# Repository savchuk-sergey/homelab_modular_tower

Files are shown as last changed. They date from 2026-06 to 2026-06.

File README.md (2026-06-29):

# Homelab Modular Tower

Parametric CadQuery engineering project for a compact 3D-printed homelab stack.

The project is engineering-first: revision-scoped specifications, explicit validation gates, serviceable module architecture, four M5 through-rods where applicable, rear service routing, low-voltage DC power planning, and Mini PC cooling priority.

Do not start CAD implementation from root `README.md` alone. Always validate the active revision-scoped specification first.

---

## Current active engineering focus: mk0.12

Active revision: `mk0.12 MVP-2M stack-through-rod`

`mk0.12` is an MVP-2M revision, not a full final tower and not a hot-swappable blade chassis. The active real modules are:

- Raspberry Pi + SSD
- Mini PC

The active architecture is stack-through-rod:

- modules are stacked on four M5 rods;
- top and bottom washers/nuts compress the stack;
- a middle module cannot be removed without loosening the stack;
- this is an accepted MVP limitation documented in the revision-scoped specification;
- primary device installation and cable routing happen before final stack compression.

### Current mk0.12 status

```text
SPECIFICATION: PASS FOR CAD SKELETON V3 INPUT
CAD IMPLEMENTATION: NOT STARTED
COUPON PARTS: BLOCKED
FULL PRINT: BLOCKED
NEXT STEP: mk0.12 CAD skeleton cleanup v3
```

The next engineering step remains `mk0.12 CAD skeleton cleanup v3`, but only after the cleanup/spec workflow is accepted. Documentation-only work must not advance `CAD IMPLEMENTATION` beyond `NOT STARTED`.

### mk0.12 read order

1. `revisions/mk0.12/README.md`
2. `revisions/mk0.12/ENGINEERING_SPEC.md`
3. `revisions/mk0.12/PARTS_SPEC.md`
4. `revisions/mk0.12/INTERFACES.md`
5. `revisions/mk0.12/VALIDATION_GATES.md`
6. `revisions/mk0.12/AGENT_RULES.md`
7. `revisions/mk0.12/PHYSICAL_TEST_PLAN.md`
8. `revisions/mk0.12/KNOWN_ISSUES.md`

If those documents are missing, incomplete, contradictory, or structurally invalid, CAD work is blocked.

---

## Source-of-truth policy

For active engineering work, source-of-truth precedence is:

1. Revision-scoped documents under `revisions/<revision>/`.
2. Root `AGENTS.md` workflow rules.
3. Legacy/reference snapshots.
4. Derived artifacts such as STEP, STL, PNG, screenshots, slicer previews, and renders.

CadQuery source files in `cad/` are the CAD source of truth. STEP/STL exports, renders, drawings, screenshots, and slicer previews are generated artifacts and must not override CadQuery source or revision-scoped specifications.

---

## Repository structure

```text
homelab_modular_tower/
  AGENTS.md                        # LLM agent workflow and hard gates
  README.md                        # repository orientation

  cad/                             # active CadQuery source
    config.py                      # parametric dimensions and revision constants
    parts/                         # part builders
    assembly/                      # assembly builders
    exporters/                     # export infrastructure
    utils/                         # geometry helpers

  revisions/
    mk0.12/                        # active revision-scoped specification
      README.md
      ENGINEERING_SPEC.md
      PARTS_SPEC.md
      INTERFACES.md
      VALIDATION_GATES.md
      PHYSICAL_TEST_PLAN.md
      AGENT_RULES.md
      KNOWN_ISSUES.md
    mk0.11/                        # historical/superseded subsystem-first workflow
    mk0.1/ ... mk0.9.3/            # historical revision documentation

  docs/
    workflow/
      subsystem_first_workflow.md  # mk0.11 historical/superseded workflow reference
    KIMI_AGENTS_SWARM_PROMPT_GUIDE.md
    ARCHITECTURE.md
    BOM.md
    POWER.md
    PRINTING.md

  reviews/                         # historical review reports and agent outputs
  drawings/                        # drawing/reference artifacts
  exports/                         # generated STEP/STL artifacts
  renders/                         # generated render artifacts
  scripts/                         # validation/export/render/review helpers
```

---

## Historical workflow note

`mk0.11` used a subsystem-first / testable CAD-first workflow. That workflow is now historical/superseded for active work unless a future revision explicitly promotes it again.

Useful historical references:

- `revisions/mk0.11/README.md`
- `revisions/mk0.11/VALIDATION_PLAN.md`
- `revisions/mk0.11/DECISIONS.md`
- `docs/workflow/subsystem_first_workflow.md`
- `drawings/mk0.10/README.md` for the cancelled drawing-first planning context

Historical documents must not be treated as active `mk0.12` requirements when they conflict with the revision-scoped `mk0.12` specification. The stricter interpretation wins until the ambiguity is resolved.

---

## Install

CadQuery is the only non-standard CAD dependency.

```powershell
python -m pip install cadquery
```

If you use Conda, the CadQuery project recommends a Conda environment:

```powershell
conda create -n cadquery cadquery -c conda-forge
conda activate cadquery
```

---

## Safe documentation checks

For documentation-only cleanup, use safe git/markdown checks only:

```powershell
git diff --stat
git diff -- README.md AGENTS.md revisions/mk0.12
```

Do not run the CAD export pipeline, render generation, STEP/STL generation, or coupon-part generation as part of documentation cleanup.

---

## CAD revision workflow

The hard gate is defined in `AGENTS.md`:

1. Complete the revision-scoped specification.
2. Validate required document structure.
3. Validate internal consistency.
4. Mark conflicts, assumptions, and unverifiable requirements explicitly.
5. Only after valid specification: allow CAD planning.
6. Only after CAD planning: allow CadQuery implementation.
7. Only after CAD validation gates: allow coupon parts.
8. Only after coupon and physical tests: allow full print.

No CAD development is allowed until the active revision specification is structurally complete and internally consistent.

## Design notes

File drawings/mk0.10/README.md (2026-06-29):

# mk0.10 Architecture Drawings — CANCELLED / LEGACY

> **Status: CANCELLED — drawing-first workflow stopped.**
>
> These SVG files are planning artifacts from the mk0.10 drawing-first
> workflow iteration. That workflow has been cancelled.
>
> **Do not continue iterating these drawings.**
> **Do not use these drawings as the source for active CAD decisions.**
>
> See `revisions/mk0.11/DECISIONS.md` — Decision D-001 for the full rationale.
> See `revisions/mk0.11/README.md` for the historical mk0.11 subsystem-first workflow.
> For current mk0.12 work, use `revisions/mk0.12/README.md` and root `AGENTS.md`.

---

## Why this workflow was cancelled

The mk0.10 SVG iteration produced technically correct but visually flat drawings
with no engineering judgment built in. Iterating on them did not unlock any design
decision that could not be read directly from `cad/config.py`. Physical prototyping
produces faster and more reliable validation than SVG drawing iteration for this
type of project.

## What these files are

| File | Sheet | Description |
|---|---|---|
| `01_architecture_layout_front.svg` | Sheet 01 | Front elevation layout |
| `02_architecture_layout_side.svg` | Sheet 02 | Side elevation layout |
| `03_module_interface_top.svg` | Sheet 03 | Module interface — top view |
| `04_module_interface_section.svg` | Sheet 04 | Module interface — cross section |
| `05_rail_carriage_section.svg` | Sheet 05 | Rail / carriage cross section |

Generated by: `scripts/generate_architecture_drawings.py` (also cancelled / legacy).

## Preservation policy

These files are preserved for historical reference.
They are not deleted, but they will not be updated.
CadQuery (`cad/config.py`) remains the source of truth for all dimensions.

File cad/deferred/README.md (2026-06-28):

# Deferred / future CAD — mk0.11 sliding carriage / rail subsystem

This folder documents and re-exports CAD that belongs to the **deferred**
sliding carriage / rail architecture.  It is preserved for future upgrade
paths but is **not active** in mk0.11.2.

## Active architecture (mk0.11.2)

`base_pedestal` + `generic_stack_module` + `top_cap`, compressed by four M5
through-rods.  See `revisions/mk0.11.2/`.

## Deferred architecture (future)

Sliding open-frame carriage on aluminum U-channel rails with POM-C shoes.
Source files remain in their original locations under `cad/parts/` and
`cad/assembly/` for backward compatibility and future rail/carriage work.

### Deferred parts

| Part | Source |
|---|---|
| `generic_module` (carriage-era shell with rail pockets) | `cad/parts/generic_module.py` |
| `generic_module_carriage` | `cad/parts/module_carriage.py` |
| `u_channel_rail_generic_module` | `cad/parts/rail_profile.py` |
| `pom_c_shoe_reference` | `cad/parts/pom_shoe.py` |

### Deferred assemblies

| Assembly | Source |
|---|---|
| `generic_module_assembly` | `cad/assembly/generic_module_assembly.py` |
| `single_module_bay_assembly` | `cad/assembly/single_module_bay_assembly.py` |

### Deferred jigs

| Jig | Source |
|---|---|
| `rail_carriage_fit_test` | `cad/jigs/rail_carriage_fit_test.py` |

## Rules

- Do not delete deferred code.
- Do not change the frozen U-channel rail standard when reactivating this path.
- Stack modules reserve future adapter zones in `generic_stack_module.py` so
  deferred carriage hardware can attach later without a full module redesign.

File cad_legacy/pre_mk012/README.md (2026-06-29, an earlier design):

# pre_mk012 CAD Legacy Archive

This directory contains CAD and CAD-pipeline files that were active before the
mk0.12 MVP-2M pre-CAD implementation cleanup.

These files are preserved for engineering history only.  They are not part of
the active mk0.12 CAD implementation path.

Active mk0.12 pre-CAD files live in:

- `cad/__init__.py`
- `cad/config.py`
- `scripts/validate_mk012_spec.py`

Do not import files from this archive into the active CAD path without an
explicit revision decision.

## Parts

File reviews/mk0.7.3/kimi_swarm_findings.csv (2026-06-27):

finding_id | severity | evidence_status | reference | affected_parts | description | why_it_matters | recommended_action
MA-003 | BLOCKER | CONFIRMED | cad/parts/service_spine.py:8-35; part_dimensions.csv | rear_service_spine_lower,rear_service_spine_upper,rear_service_spine_cover_lower,rear_service_spine_cover_upper,power_bus_panel_lower,power_bus_panel_upper,power_bus_cover_lower,power_bus_cover_upper | Both lower and upper split segments have alignment tabs at the same Z=0 location. When assembled, tabs occupy the same physical volume. | Split sections are designed to be bolted together. If tabs collide, the joint cannot be assembled. This is impossible geometry, not a fit risk. | Redesign _split_section() so only one segment has a tab and the other has a matching slot. Remove the tab from the upper segment. MA-004,BLOCKER,CONFIRMED,cad/parts/cooling.py:113-134; config.py" | bottom_filter_retainer | Corner clips are placed at Y=±61, but the retainer body is only 8 mm deep (Y=±4). Clips are 57 mm outside the body and completely detached. | The retainer's only function is to hold the filter sheet. Detached clips cannot exert any retention force. The part is non-functional as printed. | Attach clips to the retainer body with connecting geometry, or redesign the retention mechanism (e.g., sliding rail clips). ASM-001,HIGH,CONFIRMED,cad/parts/side_panels.py:198-220; tower_assembly.py:159-212; renders/assembly/left.png" | left_side_panel_lower,left_side_panel_middle,left_side_panel_upper | Left and right panels share identical geometry. Both are rotated +90° around Z. For the left panel at X=-96.5, local +Y maps to -X_global = outward. Ribs and mounting bosses face away from the tower. | The left panel mounting bosses are on the exterior (X≈-108), while the mount rail is on the interior (X=-91). There is a ~13 mm gap with no boss support. The screw head would be exposed on the exterior, requiring an overly long screw. | Change left panel rotation to -90.0° (or 270.0°) in tower_assembly.py, or create mirrored left-panel geometry in side_panels.py. MA-002,HIGH,CONFIRMED,cad/parts/rails.py:31-45; tower_assembly.py:45-58; config.py" | rail_end_mount (8 instances),metal_guide_rail | Bottom mount at Z=3.5, rail starts at Z=5.0. Mount slot is 10.8 mm tall. Rail engages only 3.5 mm of the slot. Top mount has the same 3.5 mm overlap. | 3.5 mm engagement may be insufficient to securely capture the rail end. The mount may slide off or wobble under tray load. This is a shallow engagement risk, not a complete miss. | Either move the bottom mount to Z=5.0+ so the rail starts inside the slot, or increase the slot depth to 15+ mm. ASM-002,HIGH,LIKELY,cad/parts/side_panels.py:100-113; tower_assembly.py:159-212; part_dimensions.csv" | right_side_panel_lower,right_side_panel_upper,side_panel_mount_rail | After +90° rotation, the right panel's +Y face is at X=+85 (inward). Mounting bosses extend from X=+85 to X=+91.0 (for 4 mm rib height). The mount rail is at X=+91, from +87 to +95. The bosses overlap the rail volume. | If the bosses and ribs occupy the same space as the mount rail, the parts cannot be assembled without collision. Needs verification in CAD or a physical coupon. | Verify exact boss and rib placement relative to the rail in side_panels.py. If overlap is real, reduce rib height near the rail zone or add cutouts. PE-008,HIGH,CONFIRMED,plastic_estimate.csv (sum of all rows)" | All printable plastic parts | 42 printable plastic parts total 3,732 g mesh solid volume. With slicer infill, perimeters, supports, and purge, this translates to ~4.5–5.5 kg of actual PETG filament. | For a fit-check rough mockup, this is uneconomical and slow. Print time is estimated at 80–120 hours. At typical PETG pricing, this is $90–140 in filament. | Introduce mockup-thickness parameters (e.g., MOCKUP_BASE_THICKNESS=6.0, MOCKUP_TRAY_BASE=2.0) and reduce central_bottom_fan_frame, stability wings, and tray walls for mockup prints only. PRINT-004,HIGH,LIKELY,printability_check.csv (aspect_ratio=47.5); part_dimensions.csv" | top_fan_grille | 190 × 190 × 4 mm, aspect ratio 47.5. Large thin flat part with very low thermal mass. | Corners will cool fast and contract aggressively. PETG corner lift is nearly guaranteed on a 190 mm span without aggressive bed adhesion measures. | Print flat with generous brim (10 mm+). Reduce part cooling fan to 30–40 %. Use enclosure or draft shield. Consider mouse ears at corners. PRINT-005,HIGH,LIKELY,printability_check.csv (aspect_ratio=46.0); part_dimensions.csv" | bottom_filter_frame | 138 × 138 × 3 mm, aspect ratio 46.0. Very thin sheet. | Same category as the grille: large, thin, flat. 3 mm thickness with 138 mm span is extremely prone to corner lifting in PETG. | Print flat with full brim or mouse ears at corners. No supports needed. PRINT-011,HIGH,LIKELY,part_dimensions.csv; config.py (TRAY_BASE_THICKNESS=3.0)" | external_ssd_bay,mikrotik_tray,mini_pc_tray,raspberry_pi_tray,ssd_expansion_tray,ups_power_tray | All six trays have a 3 mm base with a 172–186 × 178 mm footprint. | PETG will warp at corners on any part with a large thin base. The tray base is the single biggest warping risk in the entire project. | Mandatory brim (8–10 mm). Enclosure or heated chamber highly beneficial. Slow first layer. No supports needed for vertical walls. RAP-001,HIGH,CONFIRMED,tower_assembly.py:61-69; part_dimensions.csv" | tray_support_ledge (24 instances) | Six trays × four rails = 24 small ledges that must be placed at unique Z heights and fastened individually. | This is the highest-risk step for misassembly. A human must track 24 small parts, place them at exact heights, and fasten each without a jig or alignment helper. Disproportionately complex for a rough mockup. | Reduce to a single continuous rail support per side, or design a printed installation jig/caliper that indexes off the frame. RAP-004,HIGH,CONFIRMED,PRINTABLE_PARTS.md; NON_PRINTABLE_PARTS.md; PLACEHOLDERS.md; assembly.png" | All parts | With 109 part instances from 42 unique designs, a human cannot reliably infer build order from Python code alone. | Critical steps like rod threading, base-section bolting, and mount-rail insertion order are completely undocumented. This is a recipe for misassembly and frustration. | Produce a numbered assembly instruction sheet with stage gates (e.g., Base → Rods → Corner Blocks → Rails → Ledges → Trays → Spine → Panels → Fans → Feet). PRINT-007,HIGH,LIKELY,part_dimensions.csv" | rear_service_spine_lower,rear_service_spine_upper | 132 × 40.5 × 157.75 mm. Tall, narrow PETG print with a small footprint. | Tall narrow prints are prone to gantry-induced wobble and can detach from the bed due to leverage. 157 mm is a significant height for a narrow base. | Print with wide brim (10 mm). Slow outer wall speed (30–40 mm/s). Ensure bed is clean. Consider a raft for the lower section. PRINT-019,HIGH,LIKELY,part_dimensions.csv" | rear_service_spine_cover_lower,rear_service_spine_cover_upper | 46 × 6 × 156.75 mm. 156 mm tall with only 6 mm base thickness. | This is a very tall thin wall. If printed upright on the 46 × 6 face, PETG will almost certainly wobble or detach. | Strongly recommend printing on the 46 × 156.75 face (Z = 6 mm). This makes the part a flat plate with short layer height. Use a generous brim. PE-001,HIGH,CONFIRMED,plastic_estimate.csv (326.43 g); part_dimensions.csv (257 | 031 mm³)" | central_bottom_fan_frame | 190 × 190 × 16 mm base plate. This is 60% thicker than the BASE_STABILITY_THICKNESS=10.0 used elsewhere. | This single part consumes 8.7% of all printable plastic. The M5 rods provide the primary vertical load path. The central frame only needs to distribute the 120 mm fan mount load and support a filter frame.
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

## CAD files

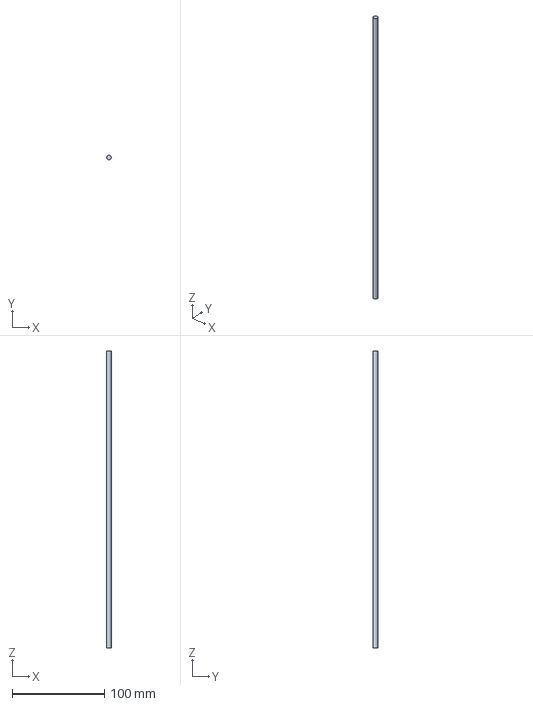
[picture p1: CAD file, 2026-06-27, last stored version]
revisions/mk0.7/review_package/exports/non_printable/metal_reference/m5_threaded_rod.step
5.00 x 5.00 x 321.5 mm

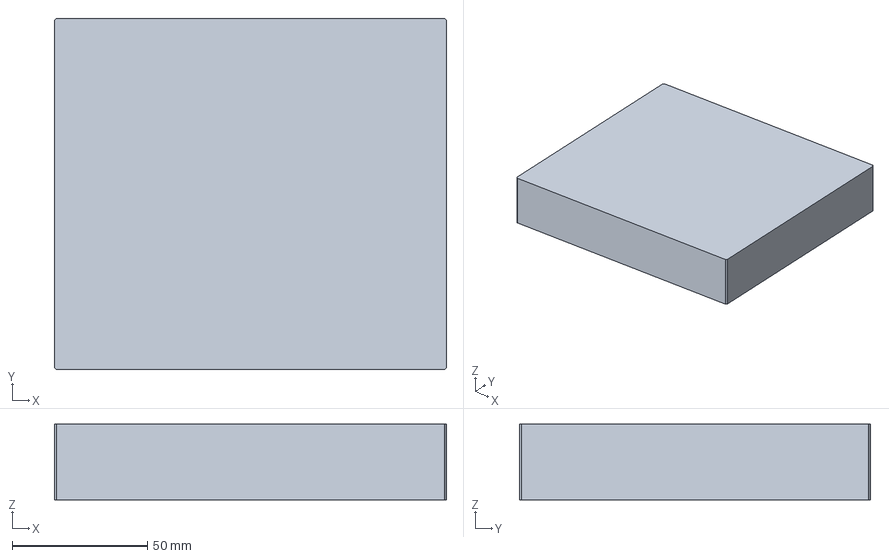
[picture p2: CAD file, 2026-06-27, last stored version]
revisions/mk0.7/review_package/exports/placeholders/devices/mini_pc_placeholder.step
145.0 x 130.0 x 28.0 mm

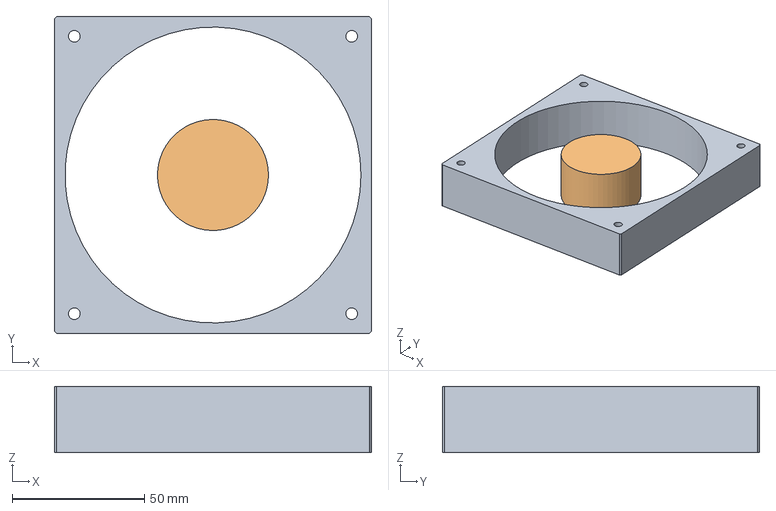
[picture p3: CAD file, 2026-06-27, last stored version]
revisions/mk0.7/review_package/exports/placeholders/fans/fan_120x120x25_placeholder.step
120.0 x 120.0 x 25.0 mm

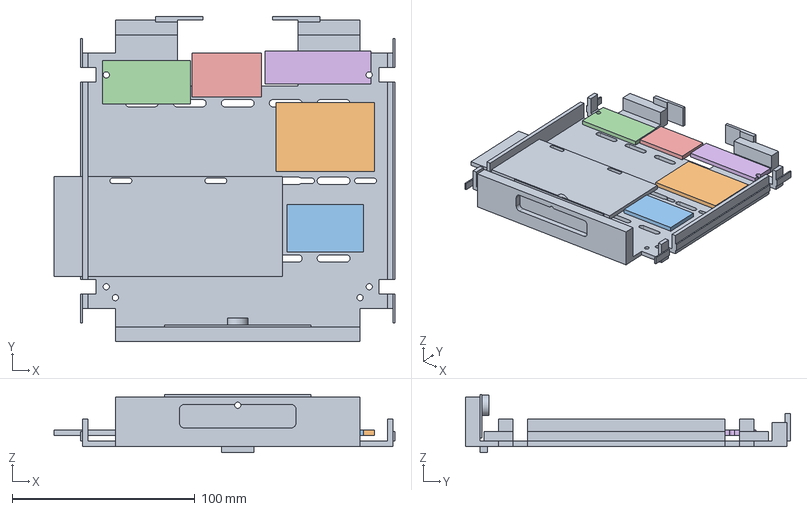
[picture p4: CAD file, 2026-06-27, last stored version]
revisions/mk0.7/review_package/exports/printable/plastic/ups_power_tray.step
186.5 x 178.0 x 32.0 mm

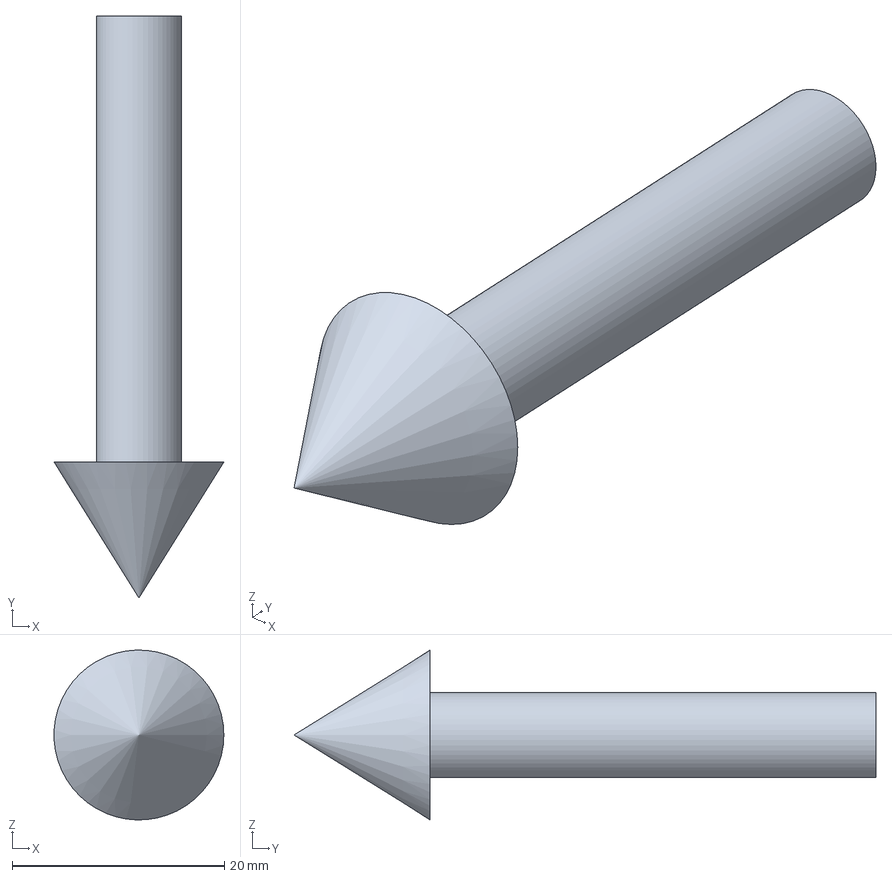
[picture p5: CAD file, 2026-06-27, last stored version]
revisions/mk0.7/review_package/exports/review/mini_pc_airflow_path_review.step
16.0 x 54.8 x 16.0 mm

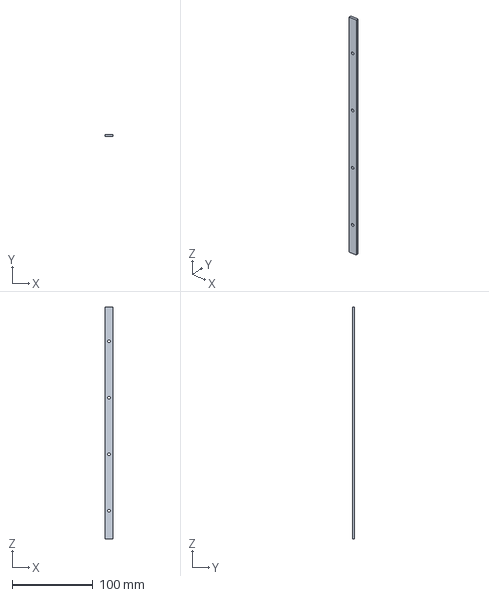
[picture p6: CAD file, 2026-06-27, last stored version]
revisions/mk0.7/review_package/exports/non_printable/metal_reference/metal_guide_rail.step
10.0 x 3.00 x 287.5 mm

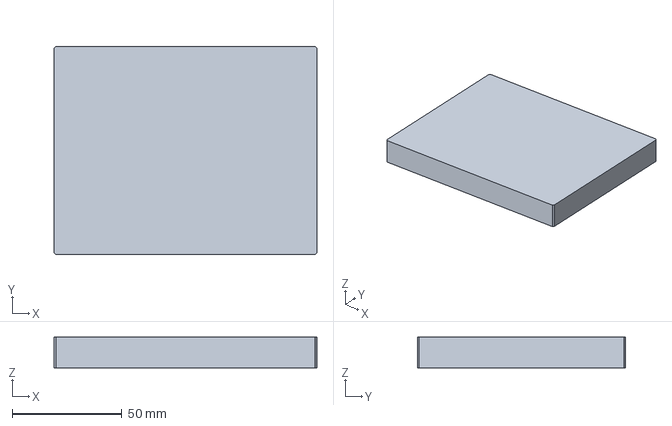
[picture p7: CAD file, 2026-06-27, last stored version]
revisions/mk0.7/review_package/exports/placeholders/devices/mikrotik_placeholder.step
120.0 x 95.0 x 14.0 mm

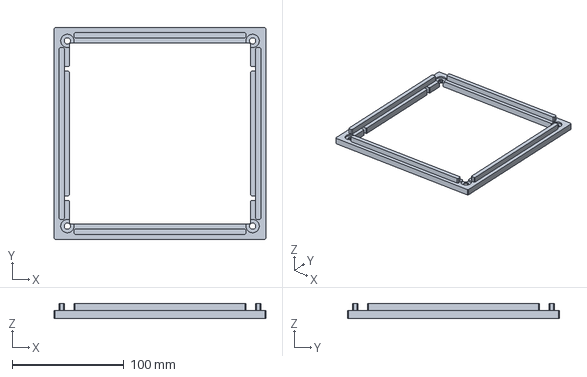
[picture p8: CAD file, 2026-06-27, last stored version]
revisions/mk0.7/review_package/exports/printable/plastic/bottom_structural_frame.step
190.0 x 190.0 x 13.0 mm

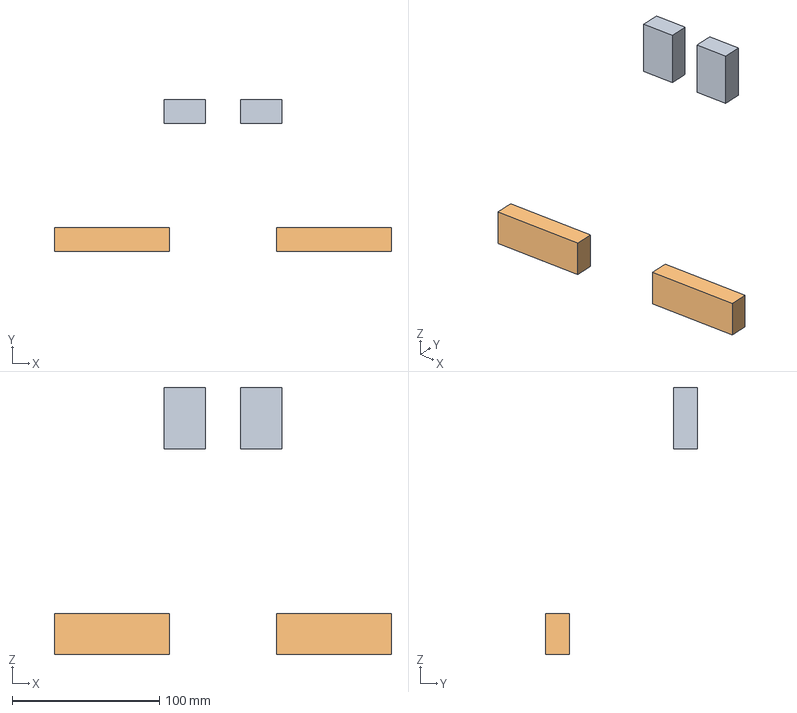
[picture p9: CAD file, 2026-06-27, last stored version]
revisions/mk0.7/review_package/exports/review/blocked_air_zones_review.step
229.0 x 103.0 x 181.8 mm

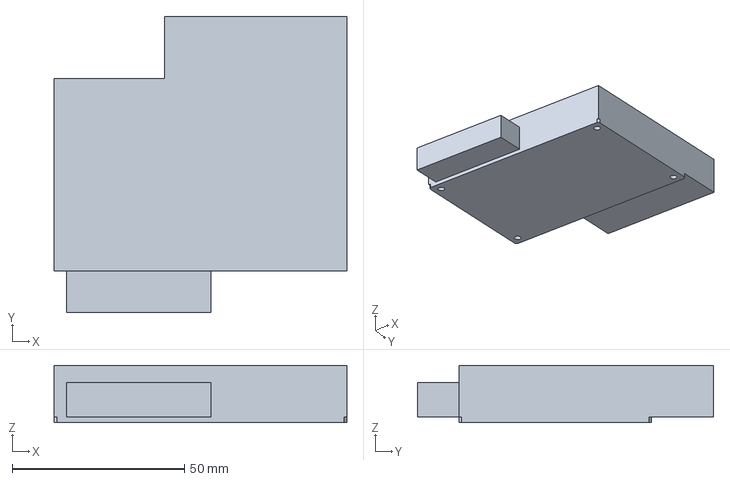
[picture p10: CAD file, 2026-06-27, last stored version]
revisions/mk0.7/review_package/exports/placeholders/devices/raspberry_pi_3b_placeholder.step
85.0 x 86.0 x 16.6 mm

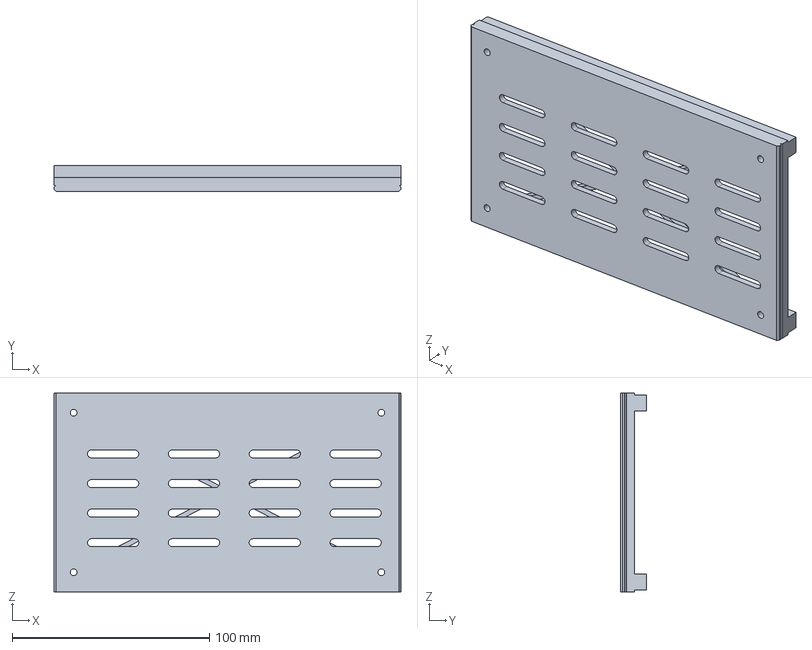
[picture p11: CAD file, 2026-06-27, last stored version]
revisions/mk0.7/review_package/exports/printable/plastic/right_side_panel_lower.step
176.0 x 13.0 x 100.9 mm

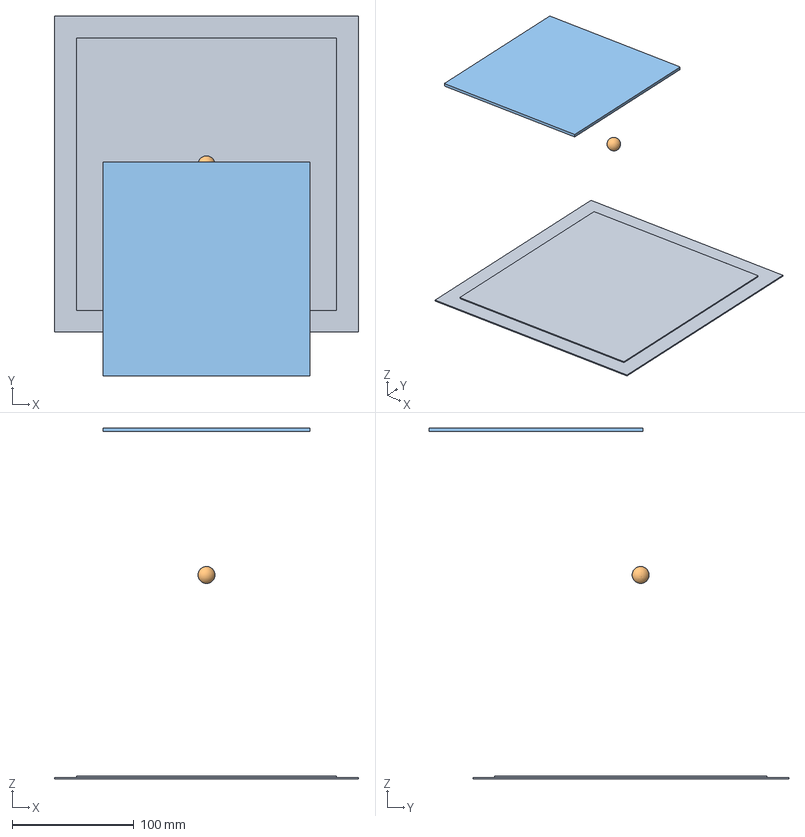
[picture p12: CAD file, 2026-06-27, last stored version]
revisions/mk0.7/review_package/exports/review/stability_review.step
250.0 x 296.0 x 288.6 mm

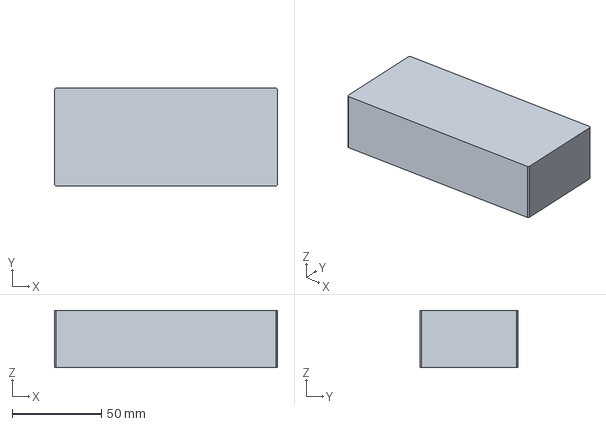
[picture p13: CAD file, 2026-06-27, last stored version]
revisions/mk0.7/review_package/exports/placeholders/devices/ups_placeholder.step
125.0 x 55.0 x 32.0 mm

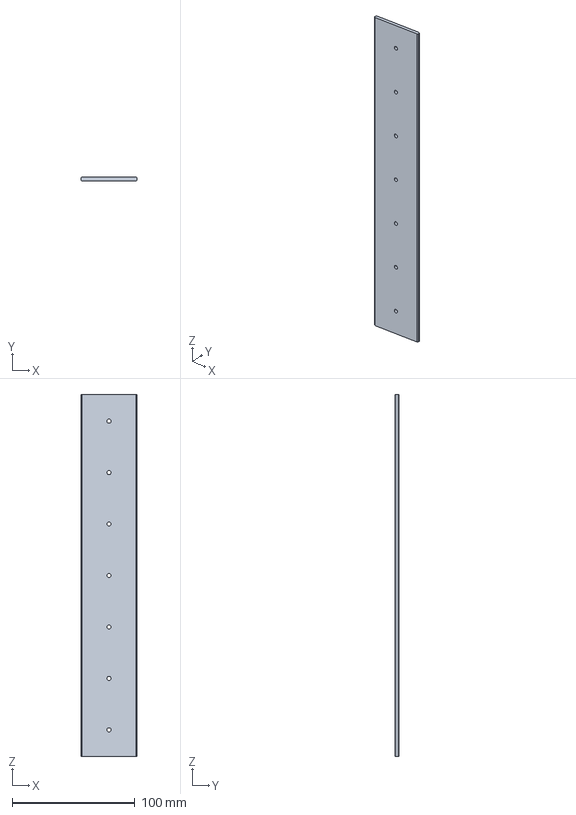
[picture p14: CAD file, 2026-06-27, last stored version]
revisions/mk0.7/review_package/exports/printable/plastic/rear_service_spine_cover.step
46.0 x 3.00 x 295.5 mm

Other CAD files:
revisions/mk0.7/review_package/exports/review/airflow_path_review.step
revisions/mk0.7/review_package/exports/placeholders/devices/ssd_expansion_placeholder.step
revisions/mk0.7/review_package/exports/printable/plastic/mini_pc_tray.step
revisions/mk0.7/review_package/exports/review/printability_layout_review.step
exports/mk0.1/step/bottom_fan_panel.step
exports/mk0.1/step/corner_block.step
exports/mk0.1/step/external_ssd_bay.step
exports/mk0.1/step/frame_bottom.step
exports/mk0.1/step/frame_top.step
exports/mk0.1/step/left_side_panel.step
exports/mk0.1/step/m5_threaded_rod.step
exports/mk0.1/step/metal_guide_rail.step
exports/mk0.1/step/mikrotik_tray.step
exports/mk0.1/step/mini_pc_airflow_duct.step
exports/mk0.1/step/mini_pc_tray.step
exports/mk0.1/step/power_bus_panel.step
exports/mk0.1/step/raspberry_pi_tray.step
exports/mk0.1/step/rear_service_spine.step
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

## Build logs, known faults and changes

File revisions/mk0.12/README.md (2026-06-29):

# mk0.12 - Revision Map

Revision: mk0.12  
Architecture: MVP-2M stack-through-rod  
Status: Revision-scoped document set active for CAD skeleton v3 input  

Related documents:
- README.md
- ENGINEERING_SPEC.md
- PARTS_SPEC.md
- INTERFACES.md
- VALIDATION_GATES.md
- PHYSICAL_TEST_PLAN.md
- AGENT_RULES.md
- KNOWN_ISSUES.md

## Status

```text
SPECIFICATION: PASS FOR CAD SKELETON V3 INPUT
CAD IMPLEMENTATION: NOT STARTED
COUPON PARTS: BLOCKED
FULL PRINT: BLOCKED
NEXT STEP: mk0.12 CAD skeleton cleanup v3
```

## Architecture

mk0.12 is an MVP-2M stack-through-rod architecture for a compact Homelab Modular Tower. The active stack is:

1. `base_pedestal`
2. `rpi_ssd_stack_module`
3. `minipc_stack_module`
4. `top_cap`

The tower uses a frozen 190 x 190 mm footprint, four M5 rods at X/Y +/-80, and a 238 mm stack height. It is not a hot-swappable blade chassis. Primary device installation and cable routing must happen before final stack compression.

Coupon parts and full print are blocked until the CAD skeleton v3 validation gates pass. Physical coupons follow CAD validation; full print follows coupon and physical validation.

## Read Order

1. ENGINEERING_SPEC.md
2. PARTS_SPEC.md
3. INTERFACES.md
4. VALIDATION_GATES.md
5. AGENT_RULES.md
6. PHYSICAL_TEST_PLAN.md
7. KNOWN_ISSUES.md

## Legacy Snapshot

`MVP_ENGINEERING_SPEC.md` remains as the consolidated legacy snapshot. These revision-scoped documents split that content by purpose without changing engineering decisions. If a requirement appears ambiguous, preserve the stricter interpretation and verify against `MVP_ENGINEERING_SPEC.md`.

The revision-scoped documents are the active source of truth for new mk0.12 CAD work.
`MVP_ENGINEERING_SPEC.md` is fallback/context only.
If the legacy snapshot conflicts with the revision-scoped documents, the revision-scoped documents win.
If ambiguity remains, preserve the stricter interpretation and validate against `VALIDATION_GATES.md`.

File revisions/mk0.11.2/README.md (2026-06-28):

# mk0.11.2 — Stack-Through-Rod Architecture

## Scope

mk0.11.2 corrects the ambiguous carriage/module direction from mk0.11 and
mk0.11.1.  The first physical prototype is a **layer-cake stack** compressed
by four M5 through-rods — not a sliding carriage prototype.

### Active architecture

```text
base_pedestal
  + generic_stack_module(s)
  + top_cap
  -> compressed by 4x M5 through-rods
```

Stack modules are printable PETG layers with:

- top/bottom interface rings and alignment features;
- M5 pass-through holes at corner posts;
- local washer compression pad zones;
- central vertical airflow opening;
- rear service reserved zone;
- internal device mounting placeholder grid;
- front handle / label zone placeholder;
- **future** carriage / side-adapter mounting zones (pads + M3 bosses only).

Primary validation assembly: `stack_test_assembly`.

### Deferred architecture

Sliding open-frame carriage on aluminum U-channel rails with POM-C shoes.
Source code is preserved under `cad/deferred/` and original part paths.
Not exported or validated as part of mk0.11.2.

---

## CAD targets (mk0.11.2)

| Target | Source |
|---|---|
| `generic_stack_module` | `cad/parts/generic_stack_module.py` |
| `base_pedestal` | `cad/parts/base_pedestal.py` |
| `top_cap` | `cad/parts/top_cap.py` |
| `stack_test_assembly` | `cad/assembly/stack_test_assembly.py` |

Export:

```text
python -m cad.export --revision mk0.11.2
```

---

## Out of scope

- Full tower CAD integration
- Active carriage, rails, or POM-C shoe sockets in stack modules
- UPS / router / Mini PC module finalization
- Rear Service Spine revision
- Changes to the frozen U-channel rail standard
- Solid floors blocking vertical airflow

---

## Relationship to prior mk0.11.x work

| Revision | Status |
|---|---|
| mk0.11 | Subsystem-first workflow; carriage/rail generic module — **superseded for active prototype** |
| mk0.11.1 | Branch work toward carriage validation — **not active in mk0.11.2** |
| mk0.11.2 | **Active**: stack-through-rod prototype with future adapter reserve |

Historical mk0.11 files (`generic_module.py`, `module_carriage.py`, bay
assemblies, fit jig) are **not deleted**.  They are marked deferred in
`cad/deferred/README.md`.

---

## Frozen decisions inherited

Same as mk0.11 / mk0.9.3 where not explicitly changed:

- CadQuery source in `cad/` is the source of truth
- M5 rods are the primary vertical load path
- PETG is connector/positioner, not sole load bearer
- Rear service zone: 30 mm reserved
- Vertical airflow: bottom intake / top exhaust concept
- All dimensions in `cad/config.py`

---

## Status

Working revision.  CAD compile and selective export are the first validation
gates.  Physical print validation follows `VALIDATION_PLAN.md`.

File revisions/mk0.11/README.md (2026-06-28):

# mk0.11 — Subsystem-First Workflow

## Why the drawing-first workflow was stopped

The mk0.10 iteration attempted to drive CAD decisions through SVG planning drawings
generated from `cad/config.py` via `scripts/generate_architecture_drawings.py`.
Five SVG sheets were produced covering architecture layout, module interface, and
rail/carriage cross-sections.

The approach was declared impractical for the following reasons:

- SVG output from a parametric generator produces technically correct but visually
  flat drawings with no engineering judgment built in.
- Drawings showed dimensions correctly but gave no feedback on printability,
  assembly clearance, or structural stiffness of individual interfaces.
- Iterating on SVG drawings delayed the first physical prototype indefinitely.
- No measurable design decision was unlocked by the drawing iteration that could
  not have been answered by reading `cad/config.py` directly.

Conclusion: SVG-only planning iterations for this project type do not justify the
effort. They will not be continued for mk0.11 or later revisions.

---

## New workflow: subsystem-first / testable CAD-first

mk0.11 adopts a subsystem-first / testable CAD-first process:

1. Design one generic device-agnostic module body / tray.
2. Design the carriage for that module (open-frame, POM-C shoes, compatible with
   existing mk0.9.3 U-channel rail standard).
3. Design and verify the rail pocket / POM-C shoe interface for that carriage.
4. Build a single-module bay test assembly (module + carriage + rails + shoes).
5. Print the generic module and carriage.
6. Physically validate: stiffness, airflow path, rear clearance, rail fit.
7. Only after the single module bay is validated, proceed to full tower integration.

Every step produces a testable artifact (a printable part or a physical
validation checkpoint), not a drawing.

---

## Scope of mk0.11

### In scope

- `cad/parts/generic_module.py` — generic removable module shell
- `cad/parts/module_carriage.py` — mk0.11 generic carriage (wraps open-frame standard)
- `cad/parts/pom_shoe.py` — standalone reference POM-C shoe geometry
- `cad/parts/rail_profile.py` — standalone reference U-channel rail profile
- `cad/jigs/rail_carriage_fit_test.py` — rail/carriage/shoe interface fit test jig
- `cad/assembly/generic_module_assembly.py` — module + carriage assembled
- `cad/assembly/single_module_bay_assembly.py` — single bay: module + rails + shoes
- `revisions/mk0.11/` — this documentation set
- `cad/config.py` — mk0.11 section appended (constants only, no changes to frozen values)

### Out of scope in mk0.11

- Full tower redesign
- UPS / power bus geometry
- Router / MikroTik module
- Mini PC module
- Rear Service Spine revision
- SVG drawings
- Decorative panels or surfaces
- Changes to the existing rail standard (frozen)
- Changes to the existing module interface standard (frozen)
- Changes to existing stable module shells (base, rpi_ssd, mini_pc, roof)

---

## Frozen decisions inherited from mk0.9.3

These decisions are not re-evaluated in mk0.11:

| Decision | Value |
|---|---|
| Source of truth | CadQuery code in `cad/` |
| Primary structural material | Metal (M5 rods, U-channel rails, top/bottom caps) |
| PETG role | Connector, positioner, service element — not primary load path |
| Rail standard | Aluminum U-channel 15×10×10×2 mm |
| Runner standard | POM-C round Ø8×12 mm, 2–3 per side |
| Rear service zone | Reserved, 30 mm deep |
| Airflow direction | Vertical, bottom intake / top exhaust |
| Configuration | All dimensions in `cad/config.py` |

---

## Status

mk0.11 is a working revision. CAD baseline is from mk0.9.3.
No changes are made to existing stable module shells or the tower assembly.

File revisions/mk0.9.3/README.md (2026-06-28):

# mk0.9.3

mk0.9.3 is a corrective CAD revision after mk0.9.2. Its purpose is to restore the CadQuery source as the reliable source of truth, make the project buildable/exportable from clean `master`, and make the active rail/carriage standard explicit.

This revision standardizes the side rail subsystem around aluminum U-channel rail `15 x 10 x 10 x 2 mm` and replaceable POM-C round shoes `8 x 12 mm`. PETG carries structure and socket geometry; it is not treated as the final sliding surface.

mk0.9.3 is not final print approval. It is buildable and exportable input for the next engineering review, slicer validation, and targeted fit tests.

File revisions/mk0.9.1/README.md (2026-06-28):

# mk0.9.1 — Corrective revision after mk0.9 review

## Summary

`mk0.9.1` is a **corrective** CAD revision.  It does not add new modules;
instead it fixes the structural and manufacturability issues that were
identified during the `mk0.9` engineering review.

## Goals

1. **Lighten** the `base_module` — remove the massive floor slab.
2. **Lighten** the `roof_module` — keep it a thin structural frame.
3. **Restore feet** — TPU foot mounts must be present for intake clearance,
   stability, and vibration isolation.
4. **Restore carriages** — every payload module must have a removable tray
   (carriage) that can slide out for service.
5. **Introduce a rail / carriage subsystem** — no more PETG-on-aluminum
   sliding surfaces.
6. **Use commercial aluminum U-channel rails** (15 × 10 × 10 × 2 mm).
7. **Use commercial POM-C Ø8 mm shoes** as the wear surface.
8. **Keep the large vertical airflow path** intact.
9. **Preserve the M5 vertical rod architecture**.
10. **Do not** implement power distribution, router, UPS, or a full rear
    service spine in this revision.

## What changed from mk0.9

| Area | mk0.9 | mk0.9.1 |
|---|---|---|
| Base | massive frame + floor ribs | frame only + fan mount + bottom grill + filter slot + foot mounts |
| Roof | already fairly light | kept light, no major change |
| Feet | present but not integrated into base module | explicitly integrated into base module |
| RPi/SSD tray | solid floor with vent slots | open-frame carriage with 4 POM-C shoes |
| Mini PC tray | solid floor with pad | open-frame carriage with 6 POM-C shoes |
| Rails | legacy 10 × 3 mm flat bar (placeholder) | aluminum U-channel 15 × 10 × 10 × 2 mm |
| Runners | none (PETG directly on metal) | perpendicular POM-C Ø8 mm replaceable shoes |
| Retention | none / glue | M3 clamp screw into PETG boss (no threading into POM-C) |
| Weight target | ≤ 900 g PETG | same, but now realistically achievable |

## What is still placeholder-based

* **Mini PC dimensions** — the mini PC carriage is sized from the current
  placeholder volume.  It will be refined in `mk1.0` after physical
  measurements.
* **Power / router / UPS modules** — reserved zones are present but no
  geometry is finalised.
* **Rear service spine** — not implemented; only structural clearances are
  kept.

## Verification

* Run `python -m cad.export --revision mk0.9.1` to export all STEP/STL files.
* Open `assembly.step` in FreeCAD / CQ-editor to inspect the full stack.
* Check that printed and non-printed parts are in separate export categories.

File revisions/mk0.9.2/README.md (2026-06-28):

# mk0.9.2 - Rail/carriage implementation fix

## Summary

`mk0.9.2` is a corrective CAD revision based on
`reviews/mk0.9.1/kimi_implementation_review.md`.

The revision keeps the mk0.9.1 module scope:

- base module;
- Raspberry Pi 3B + external SSD module;
- Mini PC placeholder module;
- roof module.

It does not implement final power distribution, router, UPS, full Rear Service
Spine, or final Mini PC tray/duct geometry.

## Confirmed changes

- `CURRENT_REVISION` is now `mk0.9.2`.
- The POM-C shoe clamp no longer uses the failing chamfer operation.
- The clamp now includes an explicit PETG heat-set insert boss volume.
- New rail/carriage dimensions were moved into `cad/config.py`.
- Active RPi/SSD and Mini PC placeholder module shells include printable
  U-channel rail pocket carriers and rail end stops.
- Aluminum U-channel rails and POM-C shoes remain exported as non-printed or
  placeholder artifacts, not printable plastic parts.
- The empty stray `revisionsmk0.9.1/` directory was removed.

## Verification

Passed on 2026-06-28:

- `python -m compileall cad scripts`
- targeted CadQuery build of both carriage factories
- targeted CadQuery build of `build_assembly()`
- `conda run -n cadquery python scripts/export_revision.py --revision mk0.9.2`
- `conda run -n cadquery python scripts/run_revision_pipeline.py --revision mk0.9.2`
- `conda run -n cadquery python scripts/render_views.py --out renders\mk0.9.2 --mode views --target all --revision mk0.9.2 --size 1200 --tolerance 2.0`

Generated evidence:

- `exports/mk0.9.2/`
- `renders/mk0.9.2/`
- `revisions/mk0.9.2/analysis/`
- `revisions/mk0.9.2/review_package/`

## Engineering status

`mk0.9.2` is a buildable and exportable corrective iteration. It is suitable
for external engineering review and partial fit/print planning, but it is not
a final print approval.

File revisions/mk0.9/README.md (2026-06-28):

# mk0.9 CAD Revision

mk0.9 is a modular architecture prototype. It converts the current tower direction into a four-module vertical platform with a shared draft interface.

mk0.9 is not the final mk1.0. The real mini PC dimensions are still unknown, so the mini PC tray, airflow duct, rear I/O cutouts, cable clearances and module height remain placeholder-based.

## Module Stack

From bottom to top:

- `01_base_module`
- `02_rpi_ssd_module`
- `03_mini_pc_placeholder_module`
- `04_roof_module`

Power distribution, router module, full rear service spine, DC UPS and final cable management are intentionally deferred.

## Implemented Scope

- Tower Module Interface v1 draft.
- Four corner M5 threaded rod zones.
- Top and bottom module interface features.
- Central airflow channel placeholder.
- Rear reserved zone for a future service spine.
- 120 mm bottom intake and 120 mm top exhaust placeholders.
- Raspberry Pi 3B, external SSD and mini PC bounding-box placeholders.

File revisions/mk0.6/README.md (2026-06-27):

# Homelab Modular Tower mk0.6

## Цель mk0.6

mk0.6 переводит mk0.5 из компоновочного прототипа в более инженерную эксплуатационную платформу. Ревизия сохраняет философию Mini Blade Tower, но усиливает задний силовой контур, делает базу более устойчивой и печатной, фиксирует единый tray-стандарт и добавляет более явное отображение power/cable management и airflow.

## Отличия от mk0.5

- `rear_service_spine` стал structural backbone: добавлены вертикальные backbone ribs, горизонтальные перемычки по уровням модулей и боковые mounting ears рядом с задним силовым контуром.
- Нижняя база разделена на `central_bottom_fan_frame`, `left_foot_extension`, `right_foot_extension`, `front_stability_wing`, `rear_stability_wing` и отдельные TPU feet.
- В `config.py` добавлены параметры устойчивости, module interface, foot extensions, mass assumptions и review margins.
- Tray-модули проходят через единый стандарт `make_standard_tray_base`, `make_tray_handle`, `make_tray_front_lock`, `make_tray_rear_stop`, `make_tray_cable_exit`, `make_module_rails`.
- Power bus получил крышку, strain relief zones, разделение signal/power и защитные бортики.
- Добавлены review-модели для устойчивости, airflow, blocked zones и printability layout.

## Закрытые проблемы mk0.5

- Скручивание: rear spine теперь механически связывает верх/низ и уровни модулей, а sectional side panels остаются shear elements.
- Rear Service Spine: силовая часть остается на месте при снятии крышки, крышка не является главным несущим элементом.
- Устойчивость: база расширена до параметрического footprint `250 x 260 mm`, высота ножек увеличена до `25 mm`, добавлена `stability_review`.
- Печатаемость базы: большая plate разбита на отдельные детали, совместимые с PETG-печатью на обычном столе.
- Tray стандарт: все существующие trays используют один общий factory path и одинаковую геометрию фиксации/ручки/заднего выхода кабеля.
- Power/cable management: power bus находится в rear spine, имеет крышку, strain relief и разделение cable zones.
- Airflow review: добавлены отдельные review views для общего вертикального потока, Mini PC duct, blocked zones и intake/exhaust clearance.

## Измененные детали

- `rear_service_spine`
- `rear_service_spine_cover`
- `power_bus_panel`
- `power_bus_cover`
- `central_bottom_fan_frame`
- `left_foot_extension`
- `right_foot_extension`
- `front_stability_wing`
- `rear_stability_wing`
- `ups_power_tray`
- `external_ssd_bay`
- `ssd_expansion_tray`
- `raspberry_pi_tray`
- `mikrotik_tray`
- `mini_pc_tray`

## Оценка печатаемости

Основной риск mk0.5 был в большой цельной base stability plate. В mk0.6 assembly использует секционную базу: центральная часть сохраняет 120 mm intake, боковые extensions отвечают за ширину опоры, переднее и заднее крыло отвечают за глубину footprint. Детали остаются плоскими, с ребрами снизу, и должны печататься PETG без цельной детали около `250 x 260 mm`.

## Оценка сборки

Сборка стала более модульной: база собирается винтами, rear spine крепится к силовому контуру, крышки rear spine и power bus снимаются отдельно. Tray-модули сохраняют фронтальное извлечение и получают задний cable exit, rear stop и front lock.

## Оценка жесткости

Жесткость повышается за счет замыкания заднего контура: M5 rods, top/bottom frames, corner blocks, structural rear spine и shear side panels работают как связанная рама. Точная FEA пока не выполнялась, поэтому вывод является инженерной оценкой по геометрии и load path, а не расчетным подтверждением.

## Оценка устойчивости

Footprint задан параметрами `base_width`, `base_depth`, `foot_extension_x`, `foot_extension_y`. Review-модель показывает условный центр масс и сценарий частично выдвинутого Mini PC tray. Оценка не заменяет физический tilt-test с установленными устройствами, особенно при тяжелом UPS.

## Known Limitations

- Нет FEA и нет экспериментального torsion/tilt-test.
- Массы модулей являются оценочными.
- Коннекторы power bus остаются placeholder footprints до выбора точных компонентов.
- Mini PC placeholder требует точных измерений конкретного устройства и его вентиляционных отверстий.
- Cable clamps показывают routing intent, но не являются финальной моделью под конкретные провода и разъемы.

## Next Steps для mk0.7

- Измерить реальные устройства и обновить placeholders.
- Выбрать конкретные DC connectors, fuse blocks и terminal blocks.
- Провести физический print-fit тест секционной базы и tray lock.
- Сделать tilt-test с UPS и частично выдвинутым Mini PC tray.
- Перейти от airflow review geometry к проверке фактических intake/exhaust clearances на конкретных устройствах.

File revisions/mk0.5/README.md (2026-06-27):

# mk0.5 - Stability and Torsional Stiffness Revision

mk0.5 is a focused engineering revision for stability and torsional stiffness. It should be reviewed through CAD assembly, generated STEP/STL parts, review renders and a partial printed test-rig before a full tower print.

Start with:

- `REVISION.md`
- `CALCULATIONS.md`
- `DECISIONS.md`
- `KNOWN_ISSUES.md`
- `CHANGELOG.md`

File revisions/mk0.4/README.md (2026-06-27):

# Homelab Modular Tower CAD Revision mk0.4

mk0.4 does not increase the base tower body height relative to mk0.3. The configured body height remains 321.5 mm without feet. The four removable feet add 25.0 mm of bottom intake clearance, so the assembled envelope with feet is expected to be about 346.5 mm before render/export tessellation margins.

mk0.4 не является финальной печатной версией.
mk0.4 является инженерной ревизией для улучшения печатопригодности, airflow и подготовки к slot-based архитектуре.

## Revision Goal

The goal of mk0.4 is to correct the main mk0.3 engineering weaknesses without turning the project into a taller two-mini-PC variant. This revision keeps the current module stack concept, improves bottom airflow, reduces large PETG panel risk, and introduces the first slot-based parameters for future modular growth.

## Changes From mk0.3

- Added a separate removable `foot` part intended for TPU printing.
- Added four feet to the assembly at the M5 rod corner positions.
- Added a 25.0 mm bottom air gap for the 120 mm intake fan.
- Replaced full-height left/right side panels in the assembly with three removable panel sections per side.
- Added slot-based configuration parameters: `MODULE_SLOT_COUNT`, `MODULE_SLOT_PITCH`, `LIGHT_MODULE_HEIGHT`, `COMPUTE_MODULE_HEIGHT`, `FRAME_SEGMENT_HEIGHT`, and `FRAME_SEGMENT_COUNT`.
- Added a separate `rear_service_spine_cover` part.
- Added service-spine section and cable-tie parameters for future segmented spine work.
- Updated the export registry with mk0.4 parts and compatibility aliases for frame and fan panel naming.

## mk0.3 Problems Addressed

- The bottom intake is no longer placed directly on the desk surface; the feet create a real intake plenum below the lower fan grille.
- Side panels are no longer large single PETG sheets in the active assembly. Each side is split into lower, middle, and upper sections.
- Side panels remain removable service/skin parts and are not required for the structural load path.
- The project now has explicit height-slot parameters for future module placement work.
- Rear service spine development is prepared through cover and cable-tie-slot parameters.

## Remaining mk0.4 Limits

- The structural skeleton is still a mk0.3-style full-height rod, rail, corner-block, top-frame, and bottom-frame assembly.
- `bottom_frame + repeated_middle_frame_segments + top_frame` is documented and parameterized, but middle frame segment parts are not yet implemented.
- Module tray placement still uses the existing `TRAY_STACK` unit layout rather than a full slot allocator.
- Side panel middle-section screw targets assume the future segment/mount standard; mk0.5 should add explicit middle segment mounting bosses or rails.
- The rear service spine is still one vertical printed part plus cover, not a fully segmented spine.
- Device placeholders remain approximate until real hardware measurements are taken.

## Why Body Height Was Not Increased

mk0.4 is focused on airflow, printability, serviceability, and future architecture. Increasing the tower now for a second mini PC would mix two separate engineering steps: stabilizing the current platform and designing a larger module stack. Keeping the base body height near mk0.3 makes changes easier to compare and avoids forcing users to reprint a taller skeleton before the segment strategy is proven.

## Future Expansion Strategy

Future revisions should migrate the load-bearing skeleton toward:

```text
bottom_frame + repeated_middle_frame_segments + top_frame
```

The intended expansion strategy is:

- Keep `bottom_frame` and `top_frame` reusable.
- Add printed `middle_frame_segment` parts when more module slots are required.
- Use longer M5 threaded rods for taller builds.
- Use additional metal guide rail length or rail sections for the expanded module stack.
- Add more side panel tiles instead of reprinting full side skins.
- Add more rear service spine sections instead of reprinting one taller spine.
- Keep cable routing inside the Rear Service Spine.
- Treat trays, covers, ducts, holders, and panel tiles as replaceable service parts.

This strategy should allow future modules to be added by changing slot/segment counts and printing only the new intermediate parts rather than replacing the whole tower skeleton.

## mk0.5 TODO

- Implement actual `middle_frame_segment` geometry with M5 rod pass-throughs, rail interfaces, and side-panel mounting points.
- Convert module placement from `TRAY_STACK` units to a stricter slot allocator.
- Split the rear service spine into repeated vertical sections with a matching segmented cover.
- Add explicit side-panel section mounting bosses on frame segments or dedicated panel rails.
- Validate fan intake clearance and pressure losses with physical measurements.
- Measure all real devices and replace placeholder envelopes.
- Add collision or clearance tests around panel sections, feet, fan grilles, and tray extraction paths.

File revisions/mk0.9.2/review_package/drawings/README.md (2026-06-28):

# mk0.9.2 drawing sheets

This folder contains generated engineering drawing sheets for the active
`mk0.9.2` CAD model.

Included:

- `assembly.png` - main assembly drawing sheet.
- `parts/*.png` - drawing sheets for non-legacy parts from
  `EXPORT_CATEGORIES`.

Excluded:

- `legacy` export-category helpers.

These drawings are generated review artifacts. CadQuery source remains the
source of truth.

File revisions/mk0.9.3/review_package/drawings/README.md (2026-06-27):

No artifacts were found for this category in the current revision workspace.

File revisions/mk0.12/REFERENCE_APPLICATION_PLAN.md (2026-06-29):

# mk0.12 Reference Application Plan

> REFERENCE/CONTEXT ONLY:
> This file is not an active requirement document for new mk0.12 CAD work.
> Use the revision-scoped document set in `revisions/mk0.12/` as the active source of truth:
> `README.md`, `ENGINEERING_SPEC.md`, `PARTS_SPEC.md`, `INTERFACES.md`,
> `VALIDATION_GATES.md`, `PHYSICAL_TEST_PLAN.md`, `AGENT_RULES.md`, and `KNOWN_ISSUES.md`.
> If this file conflicts with the active revision-scoped documents, the revision-scoped documents win.
> If a requirement is ambiguous, preserve the stricter interpretation and verify against `VALIDATION_GATES.md`.

## 1. Executive Summary

mk0.12 is planned as an MVP-2M reference-informed revision for Homelab Modular Tower. It is not a copy, fork, or adaptation of any single external project.

No external project is selected as a direct CAD base.
mk0.12 remains a custom CadQuery stack-through-rod architecture informed by selected reference patterns.

The near-term MVP remains focused on two real modules:

- Mini PC
- Raspberry Pi + SSD

The purpose of this plan is to reduce the risk of designing every subsystem from a blank page while keeping control over the Homelab Modular Tower architecture. External projects are treated as reference patterns for serviceability, printability, documentation discipline, compact device trays, and module layering. They do not override the project constraints: CadQuery remains the source of truth, dimensions belong in `cad/config.py`, and generated STEP/STL/PNG artifacts remain derived outputs.

The active architecture for the MVP is `stack-through-rod`: a vertical compressed stack made from `base_pedestal`, `rpi_ssd_stack_module`, `minipc_stack_module`, `top_cap`, four M5 threaded rods, washers, and nuts. Plastic parts provide positioning, airflow shaping, cable routing, and compression pad geometry. They must not become the only structural path.

## 2. Reference Classification

| Reference | Role | Use | Do Not Use | Status |
| --- | --- | --- | --- | --- |
| `istergiou/nas-rack` | Stackable NAS/SBC rack concept reference | Layered compact device organization, stack/slot thinking, small NAS/SBC density cues | Direct CAD base, exact dimensions, proof of airflow or cable architecture | REFERENCE ONLY |
| `ilikecake/RPi-Rack-Case` | Donor reference for Raspberry Pi / small device module planning | Raspberry Pi tray thinking, front service access, compact 1U-style device support | Whole tower architecture, mini PC thermal layout, direct geometry | GO |
| `peter-mount/pi-rack` | Printability and load-bearing reinforcement reference | Slicer assumptions, reinforced printed load zones, higher infill logic near structural features | CAD source geometry without license verification, full module architecture | PARTIAL |
| `TheCallumInglis/Rack_Mount_Pi` | Low-priority Raspberry Pi mounting reference | Pi mounting pattern sanity checks and rack-mount Pi context | Architecture, CAD base, source geometry without license verification | PARTIAL |
| `plasmadancom/HAT-RACK` | Serviceability, power separation, and industrial discipline reference | External power mindset, separated boards, DIN-like service logic, cable/power organization | Printable tower geometry, mini PC/NAS layout, direct enclosure shape | GO |
| `plasmadancom/DINPi-RACK` | Secondary industrial mounting reference | DIN/mounting mindset and dimensional drawing discipline | Tower base, module architecture, direct geometry | PARTIAL |
| `cloudmesh-community/case` | Documentation and validation process reference | Requirements-before-CAD discipline, BOM, assembly notes, physical validation cycle | Direct geometry, material strategy, laser-cut acrylic assumptions | GO |
| N5 Mini / Jack Harvest | Candidate compact mini PC + storage layout reference | Future investigation of mini PC, storage, PETG/TPU, airflow, fan, cable, and power integration | CAD base until source, license, dimensions, and adaptation path are verified | HOLD |
| `merocle/uptime-platform-for-raspberry-pi` | Low-priority Raspberry Pi rack-platform reference | Minimal context for rack-platform Pi ideas | CAD base, primary architecture, ShareAlike-derived geometry path | PARTIAL |

## 3. Reference Pattern Map

| Pattern | Source Reference | Target Area in Homelab Modular Tower | Why Useful | Risk |
| --- | --- | --- | --- | --- |
| Stackable NAS/SBC layer concept | `istergiou/nas-rack` | Overall MVP stack organization | Supports layered thinking for compact multi-device packaging | Could tempt copying a slot architecture that does not support M5 rods, rear spine, or mini PC thermals |
| Raspberry Pi / small device tray | `ilikecake/RPi-Rack-Case`, `TheCallumInglis/Rack_Mount_Pi` | `rpi_ssd_stack_module` | Gives practical cues for Pi mounting, small-device access, and compact tray constraints | Pi-only assumptions may ignore SSD, cable exit, vertical airflow, and stack compression zones |
| Front service access | `ilikecake/RPi-Rack-Case` | Pi/SSD and Mini PC module access faces | Helps preserve access to removable media, ports, and retainers | Front access must not weaken the stack interface or block airflow |
| Load-bearing print reinforcement | `peter-mount/pi-rack` | M5 rod pads, washer seats, base/top compression areas | Reinforces printed parts around real load paths instead of treating plastic as decorative shell | Overbuilding can increase print time, warping risk, and material cost |
| External power / serviceability mindset | `plasmadancom/HAT-RACK` | Power bus planning, service separation, rear reserve zone | Keeps power and service routing deliberate instead of hiding cables between modules | Industrial layout cues may be too bulky for the MVP footprint |
| Documentation and validation discipline | `cloudmesh-community/case` | Revision docs, BOM, assembly validation, test gates | Prevents CAD-first drift and forces physical checks before full print | Process overhead can delay CAD if not kept proportional to MVP scope |
| Mini PC + storage layout | N5 Mini / Jack Harvest | `minipc_stack_module`, future storage adjacency | Useful compact packaging reference for real mini PC plus storage workflows | HOLD until source, license, and dimensions are verified |
| Cable routing / rear service discipline | `plasmadancom/HAT-RACK`, current Rear Service Spine concept | Rear service reserved zone and per-module cable exits | Reduces chaotic cable paths and protects future DC bus planning | Rear zone may become overcrowded without strict reserved envelope rules |
| Future expansion without full reprint | Own stack-through-rod architecture, `istergiou/nas-rack` | Stack interface standard and module height units | Allows adding height by changing rods and adding modules instead of reprinting old modules | Middle-module removal remains limited in MVP because the stack must be loosened |

## 4. Iterative Application Plan

### Stage 0 - Documentation Freeze

Goal: freeze the rule that mk0.12 uses reference-informed design but does not copy external CAD.

Output artifacts:

- `REFERENCE_APPLICATION_PLAN.md`
- `REFERENCE_DECISIONS.md`
- `MVP_REQUIREMENTS.md`

Required decisions:

- External references are pattern libraries only.
- mk0.12 targets MVP-2M first, not a generic universal tower.
- Direct CAD import, fork, or geometry adaptation is prohibited unless license, source format, dimensions, and adaptation path are documented.
- CAD work must not start until the stack interface assumptions are written down.

### Stage 1 - Stack Interface Standard

Goal: create or describe the common stack-interface standard before module-specific CAD.

The standard must define:

- outer footprint;
- M5 rod pattern;
- washer/compression zones;
- airflow opening;
- rear service reserved zone;
- module height unit;
- top/bottom contact interface;
- future side-adapter reserve zones.

Prohibited in this stage:

- active rails;
- active sliding carriage;
- POM-C shoe sockets.

Engineering logic:

- The M5 rod pattern is a breaking interface. It must be stable before real modules are designed.
- The stack interface must reserve airflow and rear service volume from the beginning.
- Compression zones must be designed as load transfer areas, not incidental flat surfaces.

Validation gate:

- A written interface sketch/spec exists before any new part function is created.
- Every future module can identify its four rod clearances, washer no-go zones, airflow aperture, and cable exit zone.

### Stage 2 - Raspberry Pi + SSD Module Planning

Goal: plan `rpi_ssd_stack_module`.

Reference inputs:

- `ilikecake/RPi-Rack-Case`
- `TheCallumInglis/Rack_Mount_Pi`
- `HAT-RACK`

The plan must describe:

- Raspberry Pi mounting pattern;
- SSD mounting / strap area;
- cable exit to rear service zone;
- airflow clearance;
- access to SD card / USB / power if relevant;
- serviceability constraints.

Engineering logic:

- The Pi module should be a real device tray, not a placeholder shelf.
- SSD retention must be serviceable without relying on fragile snap-only plastic.
- Cable exits must point toward the rear service reserve rather than crossing the module cavity.

Validation gate:

- Pi board envelope, SSD envelope, fastener access, and cable bend space are documented.
- The module does not violate the Stage 1 stack interface.

### Stage 3 - Mini PC Module Planning

Goal: plan `minipc_stack_module`.

Reference inputs:

- N5 Mini / Jack Harvest as HOLD reference;
- `cloudmesh-community/case` for validation discipline;
- existing Homelab Modular Tower constraints.

The plan must describe:

- mini PC cradle/tray;
- strap/retainer logic;
- rear cable exit;
- heat/airflow clearance;
- center-of-mass risk;
- possibility of second mini PC in future.

Engineering logic:

- Mini PC thermal behavior dominates the MVP. It should not inherit Pi-rack assumptions.
- The module must hold device mass through a tray/strap/retainer concept compatible with M5 compression zones.
- A second future mini PC must remain possible by preserving the stack interface and module height logic.

Validation gate:

- Mini PC mass, approximate center of mass, cable exit direction, and airflow clearance are recorded before CAD.
- N5 Mini patterns remain HOLD until source/license/dimensions are verified.

### Stage 4 - Base / Top / Rod Hardware Planning

Goal: plan the structural stack assembly.

Reference inputs:

- `peter-mount/pi-rack` for load-bearing print reinforcement;
- `cloudmesh-community/case` for validation process.

The plan must describe:

- `base_pedestal`;
- `top_cap`;
- M5 rods;
- washers/nuts;
- replaceable rod length;
- TPU feet;
- future wider foot extensions;
- physical fit tests.

Engineering logic:

- Base and top parts are compression endpoints and alignment tools.
- Rod length must be replaceable so future height changes do not require reprinting existing modules.
- TPU feet and wider foot extensions must be planned as stability and vibration features, not decorative add-ons.

Validation gate:

- M5 rod clearance, washer seat diameter, nut access, and stack compression areas are coupon-tested before full print.

### Stage 5 - Rear Service Zone Planning

Goal: plan the rear service reserve.

Reference inputs:

- `HAT-RACK` for serviceability and power separation;
- current Homelab Modular Tower Rear Service Spine concept.

The plan must describe:

- rear reserved zone;
- cable windows per module;
- tie slots;
- strain relief placeholders;
- future DC power bus;
- why full-height rear spine should not be monolithic in MVP.

Engineering logic:

- MVP needs a disciplined rear reserve, but a monolithic full-height spine would make early iteration harder.
- Per-module cable windows allow each module to be tested independently.
- Tie slots and strain relief placeholders should be present early, while the final DC bus can remain a future service node.

Validation gate:

- Each MVP module has a documented rear cable exit.
- Cable routing does not pass randomly between modules.
- Future DC bus space is reserved without finalizing UPS or MikroTik geometry in mk0.12.

### Stage 6 - Physical Validation Plan

Goal: define tests before any full print.

Reference inputs:

- `cloudmesh-community/case`;
- `peter-mount/pi-rack`.

Required validation steps:

- print small coupons first;
- M5 rod clearance test;
- washer compression test;
- PETG shrink/tolerance test;
- airflow visual continuity test;
- cable routing mock test;
- mini PC weight/tilt test;
- slicer preview requirement;
- no full print before coupon validation.

Engineering logic:

- mk0.12 should move toward physical MVP confidence, not just visual CAD completion.
- Coupon tests isolate tolerance and compression risks before wasting material on large parts.
- Slicer preview is mandatory because top/bottom rings, bridges, and long thin features can fail even when the CAD model is valid.

Validation gate:

- Full MVP print is blocked until coupon results and slicer preview are documented.

## 5. Go / No-Go Rules

Do not copy external CAD geometry directly unless license, source format, dimensions, and adaptation path are verified.
Do not introduce active rails or sliding carriage in mk0.12.
Do not make rear service spine monolithic for MVP.
Do not add decorative panels before structural validation.
Do not finalize UPS/MikroTik modules in mk0.12.
Do not change M5 rod pattern after Stage 1 without documenting a breaking interface revision.

Additional gates:

- GO only if the stack interface is stable enough for both MVP modules.
- GO only if all new dimensions can be represented in `cad/config.py`.
- PARTIAL only if a reference pattern can be translated into Homelab Modular Tower constraints without importing geometry.
- HOLD if license, source format, measured dimensions, or physical adaptation path are unclear.
- NO-GO if a pattern makes middle-module access better by breaking the MVP compression stack, rod pattern, airflow path, or rear service reserve.

## 6. CAD Impact Plan

This section lists files that may appear in a future CAD iteration. They must not be created as part of this documentation-only task.

| Future File | Purpose |
| --- | --- |
| `cad/parts/stack_interface.py` | Shared stack interface definitions and helper geometry for footprint, M5 rod pattern, washer/compression zones, airflow opening, rear service reserve, and contact surfaces. |
| `cad/parts/base_pedestal.py` | Bottom compression endpoint, rod alignment base, fan/intake or clearance planning area, TPU foot interface, and future wider-foot attachment reserve. |
| `cad/parts/top_cap.py` | Top compression endpoint, rod alignment cap, exhaust/fan or airflow clearance planning area, and washer/nut service access. |
| `cad/parts/module_rpi_ssd.py` | Raspberry Pi + SSD stack module with board mounting, SSD retention, airflow clearance, rear cable exit, and service access. |
| `cad/parts/module_minipc.py` | Mini PC stack module with cradle/tray, strap or retainer logic, heat/airflow clearance, rear cable exit, and center-of-mass considerations. |
| `cad/assembly/mvp_2_module_stack.py` | MVP-2M assembly showing `base_pedestal`, `rpi_ssd_stack_module`, `minipc_stack_module`, `top_cap`, rods, washers, and nuts. |

CAD rules for the future implementation:

- All dimensions must be defined in `cad/config.py`.
- Each part must expose separate part functions.
- Assembly must stay separate from part definitions.
- No magic numbers are allowed inside part functions.
- Export artifacts are derived and must not become the source of truth.
- STEP/STL/PNG generation should happen only after the planned CAD stage needs it.

## 7. Risks and Mitigations

| Risk | Source | Impact | Mitigation | Validation |
| --- | --- | --- | --- | --- |
| Reference projects are not direct CAD bases | External reference audit | Copying geometry could break project architecture and licensing assumptions | Treat references as patterns only | Review Stage 0 decisions before CAD starts |
| N5 Mini source/license not verified | N5 Mini / Jack Harvest | Mini PC/storage patterns may be unusable legally or technically | Keep as HOLD until source, license, and dimensions are verified | Record verification result before using any specific geometry idea |
| Stack-through-rod limits serviceability | Own MVP architecture | Middle modules cannot be removed without loosening the stack | Accept for MVP and document as known tradeoff | Assembly/service mock test |
| Adding modules requires longer rods | Own MVP architecture | Future expansion changes hardware length and stack compression setup | Use replaceable rods and stable module height units | Rod length planning table in future `MVP_REQUIREMENTS.md` |
| Rear cable zone may become overcrowded | Rear Service Spine concept | Cables may block airflow or module fit | Reserve rear envelope and define per-module windows | Cable routing mock test |
| Mini PC heat may dominate airflow | Mini PC module | Thermal throttling or heat soak in upper modules | Prioritize mini PC airflow clearance and avoid Pi-rack assumptions | Airflow visual continuity test and later thermal observation |
| Top/bottom rings may create print bridges | Base/top stack geometry | Failed prints, sagging bridges, poor washer seats | Add slicer preview gate and avoid unsupported spans | Slicer preview plus coupon print |
| PETG shrink may affect M5 clearance | PETG printing | Rods may bind or washer seats may not fit | Coupon-test rod holes and washer pockets before full print | M5 rod clearance and washer compression coupons |
| Center of mass may rise with future modules | Stack expansion | Tower tipping risk increases | Plan TPU feet and future wider foot extensions | Mini PC weight/tilt test |
| Future UPS module may require bottom placement | Power architecture | Later UPS module may force stack order changes | Do not finalize UPS in mk0.12; preserve bottom-placement option | Future revision requirement review |

## 8. Final Recommendation

Proceed with mk0.12 as MVP-2M Reference-Informed Stack.
Use external projects only as pattern references.
Do not fork or adapt any external CAD as the primary base.
First CAD implementation should target stack interface + two real modules, not a generic universal module.

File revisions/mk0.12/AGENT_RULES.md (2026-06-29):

# mk0.12 - Agent Rules

Revision: mk0.12  
Architecture: MVP-2M stack-through-rod  
Status: ACTIVE AGENT INSTRUCTIONS FOR CAD SKELETON V3 WORK  

Related documents:
- README.md
- ENGINEERING_SPEC.md
- PARTS_SPEC.md
- INTERFACES.md
- VALIDATION_GATES.md
- PHYSICAL_TEST_PLAN.md
- AGENT_RULES.md
- KNOWN_ISSUES.md

## Recommended Agent Workflow

1. Read README.md.
2. Read ENGINEERING_SPEC.md.
3. Read PARTS_SPEC.md and INTERFACES.md.
4. Read VALIDATION_GATES.md before changing CAD.
5. Read AGENT_RULES.md before implementing.
6. After CAD changes, produce validation report against VALIDATION_GATES.md.
7. Do not continue to coupon parts unless all required gates pass.

## Source of Truth

- CadQuery is the CAD source of truth.
- All dimensions must live in `cad/config.py`.
- No magic numbers inside part functions.
- Each part must have a separate builder function.
- Assembly must be separate from part definitions.
- STEP/STL/PNG are derived artifacts.
- Do not treat generated exports or renders as source of truth.

## Builder Separation

- Printable builders return printable plastic only.
- Reference builders return review/assembly geometry only.
- Do not include device placeholders in printable STL.
- Do not include rods, washers, nuts, or fan placeholders in printable STL.
- Fan screw holes/bosses are printable geometry only if fan mounting is active in that part.
- TPU feet are separate TPU printable parts, not part of PETG `base_pedestal`.

## Geometry Rules

- Do not move M5 rods unless the task explicitly says so.
- Do not exceed the 190 x 190 active PETG stack footprint.
- Do not treat the fan-compatible 120 x 120 zone as a full square cutout.
- Do not treat distributed airflow as a required empty center shaft.
- Do not create decorative ribs.
- Do not create outward star ribs from M5 compression islands.
- Do not create dangling/floating ribs.
- Every rib must have valid endpoints.
- Do not block required airflow, rear service, cable, mounting, retainer, or tool access windows.
- Declare print orientation for each printable part.

## Validation Discipline

- Mark uncertain items as NOT VERIFIED instead of silently assuming.
- Preserve PASS/PARTIAL/FAIL/NOT VERIFIED status semantics.
- Produce evidence for validation gates after CAD changes.
- Do not proceed to coupon parts unless CAD skeleton v3 gates pass.
- Do not proceed to full print unless CAD validation and physical validation pass.

## Revision History Discipline

- Do not alter old revision history to pretend previous states were different.
- Use `KNOWN_ISSUES.md` for historical failures and risks.
- Keep `MVP_ENGINEERING_SPEC.md` as the consolidated legacy snapshot unless a task explicitly asks to replace it.

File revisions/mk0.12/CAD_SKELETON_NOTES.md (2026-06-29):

# mk0.12 CAD Skeleton Notes

> NOTE:
> This is a legacy/historical CAD skeleton note.
> It is not the active CAD skeleton v3 status.
> The active source for mk0.12 CAD skeleton v3 input is the revision-scoped document set:
> `README.md`, `ENGINEERING_SPEC.md`, `PARTS_SPEC.md`, `INTERFACES.md`,
> `VALIDATION_GATES.md`, `PHYSICAL_TEST_PLAN.md`, `AGENT_RULES.md`, and `KNOWN_ISSUES.md`.
> Coupon parts remain BLOCKED until CAD skeleton v3 passes `VALIDATION_GATES.md`.

## Implemented

A legacy CAD skeleton snapshot for `mk0.12 MVP-2M stack-through-rod` was implemented in an earlier iteration.
This note is historical and must not be treated as active CAD skeleton v3 status.

Active stack order:

```text
base_pedestal:        Z 0..32
rpi_ssd_stack_module: Z 32..107
minipc_stack_module:  Z 107..212
top_cap:              Z 212..238
```

Historical CAD files from the legacy skeleton snapshot:

- `cad/parts/stack_interface.py`
- `cad/parts/base_pedestal.py`
- `cad/parts/module_rpi_ssd.py`
- `cad/parts/module_minipc.py`
- `cad/parts/top_cap.py`
- `cad/assembly/mvp_2_module_stack.py`

The assembly includes four non-printed M5 rod placeholders at `(+/-80, +/-80)`.

## Skeleton / Placeholder Scope

This is not final production CAD.  The model currently validates the stack footprint, M5 through-rod pattern, washer seats, compression-pad zones, fan-compatible base/top openings, rear service reserved zone, device envelopes, and basic Z alignment.

Device placeholders:

- Raspberry Pi 3B clearance envelope and board marker.
- External SSD preferred envelope at the active mk0.12 position.
- Mini PC physical placeholder and clearance outline.

Airflow is represented as distributed relief / bypass geometry.  The model intentionally does not create a mandatory empty `120 x 120` vertical shaft.

Fan-compatible openings use circular cutouts sized from `FAN_AIRFLOW_CUTOUT_DIAMETER_MAX`, preserving screw-boss material around the `105 x 105` fan pattern.

## Validation

Passed:

```text
python scripts/validate_mk012_spec.py
Summary: 0 FAIL, 5 PARTIAL, 11 PASS
```

CadQuery smoke-test passed in the project CadQuery environment:

```text
conda run -n cadquery python -c "from cad.assembly.mvp_2_module_stack import build_mvp_2_module_stack; build_mvp_2_module_stack(); print('OK')"
OK
```

## Remaining PARTIAL Items

The following risks remain intentionally open:

- PETG washer seat compression.
- Actual cable bend radius and real cable bundle thickness.
- Mini PC thermal behavior.
- Nut/tool access until physical/CAD access mock validation.
- Fan cutout / screw boss review until slicer review.
- SSD strap/rib final geometry.

## Intentionally Not Implemented

The skeleton does not implement:

- final ducts;
- decorative side panels;
- active rails;
- sliding carriage;
- POM-C shoe sockets;
- UPS module;
- MikroTik module;
- final cable-management spine;
- STEP/STL/PNG final exports.

## Print Status

Full print is not allowed for this revision state.

Superseded status: this legacy skeleton note is not sufficient for coupon parts or full print.
Current active status is defined by `README.md` and `VALIDATION_GATES.md`.
CAD skeleton v3 must still pass the revision-scoped validation gates before coupon parts.

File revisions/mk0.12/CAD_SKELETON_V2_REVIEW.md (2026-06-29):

# mk0.12 CAD Skeleton V2 Review

> NOTE:
> This review is a historical CAD skeleton v2 snapshot.
> It is superseded by the mk0.12 revision-scoped documents in this directory.
> Later inspection found footprint, rib-topology, and STL-topology blockers.
> Coupon parts remain BLOCKED until CAD skeleton v3 passes `VALIDATION_GATES.md`.

## Summary

mk0.12 CAD skeleton cleanup v2 replaces the previous monolithic placeholder-heavy geometry with printable-only ribbed-frame / open-tray builders and separate non-printable reference geometry.

Result:

- `scripts/validate_mk012_spec.py`: 0 FAIL, 5 PARTIAL, 11 PASS.
- `scripts/validate_mk012_cad_skeleton.py`: 0 FAIL, 0 PARTIAL, 29 PASS.
- Historical result at the time of this review: coupon parts were considered next as CAD skeleton validation coupons, not as final production STL release.
- Superseding status: this conclusion is no longer active; coupon parts are BLOCKED until CAD skeleton v3 passes `VALIDATION_GATES.md`.

## Files Changed

- `cad/config.py`
- `cad/parts/stack_interface.py`
- `cad/parts/base_pedestal.py`
- `cad/parts/module_rpi_ssd.py`
- `cad/parts/module_minipc.py`
- `cad/parts/top_cap.py`
- `cad/parts/reference_geometry.py`
- `cad/assembly/mvp_2_module_stack.py`
- `scripts/validate_mk012_cad_skeleton.py`
- `scripts/export_mk012_visual_models.py`
- `scripts/render_mk012_review_views.py`
- `revisions/mk0.12/CAD_SKELETON_V2_REVIEW.md`

## Current Active CAD Structure

Printable builders:

- `build_base_pedestal()`
- `build_rpi_ssd_stack_module()`
- `build_minipc_stack_module()`
- `build_top_cap()`

Reference-only builders:

- `build_rpi3b_placeholder()`
- `build_external_ssd_placeholder()`
- `build_minipc_placeholder()`
- `build_m5_rods_placeholder()`
- `build_washers_placeholder()`
- `build_nuts_placeholder()`

Assembly:

- `cad/assembly/mvp_2_module_stack.py`

## Printable / Reference Separation Result

PASS.

Printable part builders return printable plastic only. Raspberry Pi, SSD, Mini PC, M5 rods, washers, and nuts are separated into `cad/parts/reference_geometry.py` and are only added by the assembly for review.

STL review exports include only printable parts:

- `base_pedestal.stl`
- `rpi_ssd_stack_module.stl`
- `minipc_stack_module.stl`
- `top_cap.stl`

## Connected Component Result

| Part | Connected printable solids |
| --- | ---: |
| `base_pedestal` | 1 |
| `rpi_ssd_stack_module` | 1 |
| `minipc_stack_module` | 1 |
| `top_cap` | 1 |

## Mass Estimate

PETG density: `1.27 g/cm3`.

| Part | Estimate | Budget result |
| --- | ---: | --- |
| `base_pedestal` | 202.7 g | PASS, target 120-220 g |
| `rpi_ssd_stack_module` | 289.0 g | PASS, target 150-300 g |
| `minipc_stack_module` | 379.4 g | PASS, target 250-450 g |
| `top_cap` | 187.9 g | PASS, target 100-200 g |
| Total printed PETG | 1059.1 g | PASS, total target 620-1170 g |

## Effective Airflow Open Area

| Part | Effective area | Result |
| --- | ---: | --- |
| `base_pedestal` | 8411 mm2 | PASS |
| `rpi_ssd_stack_module` | 10964 mm2 | PASS |
| `minipc_stack_module` | 18060 mm2 | PASS |
| `top_cap` | 8411 mm2 | PASS |

These are geometric sanity estimates, not CFD or thermal validation.

## Cable Window Checks

| Window | Size | Result |
| --- | ---: | --- |
| Rear service window | 120 x 20 mm | PASS |
| RPi/SSD cable window | 28 x 18 mm | PASS |
| Mini PC rear cable exit | 70 x 22 mm | PASS |

Mini PC rear cable exit height is above the 20 mm minimum.

## Rib Load-Path Review

PASS.

Each printable part includes:

- outer perimeter frame;
- four M5 compression islands at +/-80 mm;
- ribs from compression islands to adjacent frame walls;
- at least two transverse ribs;
- at least two longitudinal ribs;
- framed fan/rear-service/cable openings where applicable.

Device supports use ribs, bosses, rails, retainers, and local anchors instead of solid device trays.

## Tool / Finger Access Review

| Feature | Result |
| --- | --- |
| RPi M2.5 boss access envelope | PASS, 8 mm represented |
| SSD strap pull-tab access | PASS, 15 x 20 mm reserved |
| Mini PC retainer/finger access | PASS, 18 mm finger slot and 10 mm clearance represented |

Access remains a skeleton geometry review result. Hardware mock validation is still required.

## Stack Assembly Order Notes

Assembly service order is documented in `cad/assembly/mvp_2_module_stack.py`:

1. Install devices into modules before final stack compression.
2. Route Pi/SSD/Mini PC cables to rear service windows before final compression.
3. Stack modules on M5 rods.
4. Verify no cable collision with rear rod keepouts.
5. Hand-tight compression only.

## Validation Command Results

```text
C:\Users\ghery\miniforge3\envs\cadquery\python.exe scripts\validate_mk012_spec.py
Summary: 0 FAIL, 5 PARTIAL, 11 PASS

C:\Users\ghery\miniforge3\envs\cadquery\python.exe scripts\validate_mk012_cad_skeleton.py
Summary: 0 FAIL, 0 PARTIAL, 29 PASS
```

## Generated Renders / Exports

Review exports:

- `exports/mk0.12/review/step/`
- `exports/mk0.12/review/stl/`
- `exports/mk0.12/review/EXPORT_MANIFEST.md`

Review renders:

- `renders/mk0.12/assembly_front.png`
- `renders/mk0.12/assembly_rear.png`
- `renders/mk0.12/assembly_left.png`
- `renders/mk0.12/assembly_right.png`
- `renders/mk0.12/assembly_top.png`
- `renders/mk0.12/assembly_iso.png`
- `renders/mk0.12/base_pedestal_top.png`
- `renders/mk0.12/base_pedestal_iso.png`
- `renders/mk0.12/rpi_ssd_stack_module_top.png`
- `renders/mk0.12/rpi_ssd_stack_module_iso.png`
- `renders/mk0.12/minipc_stack_module_top.png`
- `renders/mk0.12/minipc_stack_module_iso.png`
- `renders/mk0.12/top_cap_top.png`
- `renders/mk0.12/top_cap_iso.png`
- `renders/mk0.12/rpi_ssd_stack_module_xy_edges.png`
- `renders/mk0.12/minipc_stack_module_xy_edges.png`
- `renders/mk0.12/rear_service_windows_check.png`
- `renders/mk0.12/airflow_open_area_check.png`

## Remaining PARTIAL / NOT VERIFIED Items

- PETG compression around washer seats remains PARTIAL until M5 corner coupon testing.
- Fan screw boss material remains PARTIAL until slicer/CAD review with actual fan screw hardware.
- Rear cable routing around rods remains PARTIAL until cable coupon and real cable bend tests.
- Real cable bundle thickness, connector strain relief, and tie routing remain PARTIAL.
- SSD strap geometry is still skeleton-level and needs hardware/cable mock review.
- Mini PC thermal behavior remains NOT VERIFIED; current airflow result is geometric only.
- Nut/tool access remains NOT VERIFIED until hardware mock.

## Recommendation

SUPERSEDED HISTORICAL RECOMMENDATION FROM V2 REVIEW.

This historical recommendation is no longer active. Later inspection found footprint, rib-topology, and STL-topology blockers. Coupon parts remain BLOCKED until CAD skeleton v3 passes `VALIDATION_GATES.md`.

Do not treat the review STL files as final production exports.

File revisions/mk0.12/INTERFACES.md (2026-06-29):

# mk0.12 - Interfaces

Revision: mk0.12  
Architecture: MVP-2M stack-through-rod  
Status: INTERFACE CONTRACTS READY FOR CAD SKELETON V3  

Related documents:
- README.md
- ENGINEERING_SPEC.md
- PARTS_SPEC.md
- INTERFACES.md
- VALIDATION_GATES.md
- PHYSICAL_TEST_PLAN.md
- AGENT_RULES.md
- KNOWN_ISSUES.md

Allowed status values:

```text
PASS
PARTIAL
FAIL
NOT VERIFIED
```

## Stable Interface Table

| Interface | Components | Geometry | Constraint | Status |
| --- | --- | --- | --- | --- |
| Base <-> RPi/SSD module | `base_pedestal`, `rpi_ssd_stack_module` | Contact plane at Z = 32; footprint 190 x 190; M5 holes at +/-80 X/Y | Planes must mate without device protrusion below RPi module | PASS |
| RPi/SSD module <-> Mini PC module | `rpi_ssd_stack_module`, `minipc_stack_module` | Contact plane at Z = 107; same M5 pattern and compression pads | Pi/SSD cable exits must stay below or inside module envelope | PARTIAL |
| Mini PC module <-> Top cap | `minipc_stack_module`, `top_cap` | Contact plane at Z = 212; same M5 pattern and compression pads | Mini PC top clearance must remain below Z = 212 | PASS by envelope assumption |
| M5 rods <-> all stack layers | rods, all printed layers | Four clearance holes diameter 5.6 at (-80,-80), (80,-80), (-80,80), (80,80) | Rod pattern must not change after spec freeze | PASS |
| Rear service zone <-> all modules | all printed layers | Y +65 to +95, depth 30, continuous Z 0 to 238 | Cable windows per module; no monolithic spine in MVP | PARTIAL |
| Fan-aligned inlet/outlet + distributed internal airflow <-> base/modules/top | base, modules, top | Base/top 120 x 120 fan-compatible zones; internal modules use equivalent distributed airflow through real openings | Devices may overlap the centered XY zone only if raised/perforated/bypass/ducted airflow is preserved as open geometry | PARTIAL |
| Printable geometry <-> reference geometry | printed parts, placeholders, hardware references | Printable STL contains only plastic body; assembly may include reference geometry | Device/hardware/fan placeholders must be separate from printable builders | NOT VERIFIED |
| Mounting/service access <-> device modules | `rpi_ssd_stack_module`, `minipc_stack_module` | Top/front/side tool access windows; rear cable exits before stack compression | Devices, retainers, straps, bosses, and cables must be reachable without cutting plastic | NOT VERIFIED |
| Washer/nut <-> base/top | rods, washers, nuts, `base_pedestal`, `top_cap` | Washer seat diameter 13, depth 1.2, centered on M5 holes | Seat must remain within corner pad and tool access zone | PARTIAL |
| Future side-adapter zones <-> modules | future adapters, stack modules | Reserved outside active MVP device/airflow zones, no active rails | Must not affect MVP M5 pattern | NOT VERIFIED |

## Assembly Plane Interfaces

- Base top plane Z = 32 must align with RPi/SSD bottom plane.
- RPi/SSD top plane Z = 107 must align with Mini PC bottom plane.
- Mini PC top plane Z = 212 must align with top cap bottom plane.
- Total stack height is 238 mm.

## M5 Stack Interface

All stack layers use M5 clearance holes diameter 5.6 at:

```text
(-80, -80)
(+80, -80)
(-80, +80)
(+80, +80)
```

The M5 rod pattern must not move unless a future task explicitly changes the revision architecture.

## Rear Service Interface

The rear service zone is Y +65..+95. It is continuous in Z from 0 to 238, but segmented in XY around rear rods and compression pads.

Preferred conservative primary cable corridor:

```text
PRIMARY_REAR_CABLE_CORRIDOR_X_MIN_PREFERRED = -60
PRIMARY_REAR_CABLE_CORRIDOR_X_MAX_PREFERRED = +60
PRIMARY_REAR_CABLE_CORRIDOR_X_MIN_ABSOLUTE_ASSUMPTION = -65
PRIMARY_REAR_CABLE_CORRIDOR_X_MAX_ABSOLUTE_ASSUMPTION = +65
```

Rear service represented only by annotation is FAIL. Every module must provide real rear service windows.

## Distributed Airflow Interface

Do not describe this interface as a required empty center shaft. The active interface is fan-aligned inlet/outlet plus distributed internal airflow.

Base/top fan-compatible zones are 120 x 120 mm. Actual cutouts are separate geometry and must preserve fan screw boss material. Internal module airflow can use raised supports, perforations, side bypass, bottom gaps, or ducted/split airflow.

Airflow represented only by annotation is FAIL.

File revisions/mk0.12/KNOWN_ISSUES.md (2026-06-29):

# mk0.12 - Known Issues

Revision: mk0.12  
Architecture: MVP-2M stack-through-rod  
Status: HISTORICAL FAILURES AND RISKS FOR CAD SKELETON V3  

Related documents:
- README.md
- ENGINEERING_SPEC.md
- PARTS_SPEC.md
- INTERFACES.md
- VALIDATION_GATES.md
- PHYSICAL_TEST_PLAN.md
- AGENT_RULES.md
- KNOWN_ISSUES.md

## Historical CAD Skeleton v2 Failures

`v2` references in this document are historical previous failures only. They are not active future implementation names.

- Previous CAD skeleton v2 expanded printable parts to approximately 205 x 205 mm.
- `minipc_stack_module` exceeded the footprint in Y.
- Outward ribs/tabs appeared from M5 rod guide/compression islands.
- Some ribs looked hanging, floating, or unfinished.
- Rib structure looked automatically generated and not load-path-aware.
- There was no guarantee that every rib had two valid endpoints.
- `rpi_ssd_stack_module` was not watertight.
- Coupon parts were blocked.
- Kilogram-scale or near-solid skeleton behavior was a design failure.

## Risks Not To Repeat

- Fan zone interpreted as a full 120 x 120 square cutout.
- Distributed airflow interpreted as a required empty center shaft.
- Rear service represented only as annotation.
- Airflow represented only as annotation.
- Reference geometry included in printable STL.
- TPU feet merged into PETG `base_pedestal` STL.
- Active PETG features protruding outside the frozen footprint.
- M5 compression island ribs generated radially in all directions.
- Rib endpoints connected only to reference geometry.
- Cable, airflow, rear service, mounting, retainer, or tool access blocked by ribs.

## Current Blocking Status

```text
COUPON PARTS: BLOCKED until CAD skeleton v3 passes validation.
FULL PRINT: BLOCKED until CAD skeleton v3 and physical validation pass.
NEXT STEP: mk0.12 CAD skeleton cleanup v3
```

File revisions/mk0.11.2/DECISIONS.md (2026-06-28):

# mk0.11.2 Engineering Decisions

## D-009: Stack-through-rod architecture for first prototype

**Decision:** mk0.11.2 uses stack-through-rod architecture.  Modules are
stackable layers compressed by four M5 threaded rods between `base_pedestal`
and `top_cap`.  Sliding carriage/rail system is deferred.  Each stack module
reserves future carriage/adapter mounting zones.

**Reason:** This keeps the first prototype simple, stiff, printable, and
testable while preserving an upgrade path toward slide-out serviceability.

**Trade-off:** Middle module removal requires loosening/disassembling the
stack in mk0.11.2.  Independent module extraction is deferred.

**Consequence:**

- Active CAD: `generic_stack_module`, `base_pedestal`, `top_cap`,
  `stack_test_assembly`.
- Deferred CAD: `generic_module` (rail-pocket era), carriage, rails, bay
  assemblies — see `cad/deferred/README.md`.

---

## D-010: generic_stack_module replaces generic_module as active target

**Decision:** New part file `cad/parts/generic_stack_module.py` is the active
module shell.  `cad/parts/generic_module.py` is preserved unchanged as the
deferred carriage-era shell with rail pockets.

**Reason:** Renaming in place would rewrite mk0.11 history and break deferred
rail validation geometry.  A separate file makes the architecture correction
explicit without retroactive edits.

---

## D-011: Future carriage zones are placeholders only

**Decision:** Stack modules include reinforced side pads, M3 insert bosses,
and bottom adapter pad placeholders at future rail lateral positions.  No
POM-C shoe sockets, no U-channel pockets, no sliding assembly geometry.

**Reason:** Preserves a future side-adapter upgrade path without implementing
or validating the deferred rail subsystem in mk0.11.2.

**Constraints:** Future zones must not interfere with M5 rods, central airflow,
or rear service zone.

---

## D-012: No full tower redesign in mk0.11.2

**Decision:** `tower_assembly.py` remains unchanged.  Validation is limited
to `stack_test_assembly`.

**Reason:** Same rationale as D-006 in mk0.11 — validate the subsystem before
integrating into the full tower stack.

---

## D-013: FUTURE_CARRIAGE_PAD_X_OFFSET added to config.py (decoupling fix)

**Decision:** Added named constant `FUTURE_CARRIAGE_PAD_X_OFFSET` to the
mk0.11.2 section of `cad/config.py`.  Removed the `rails` module import from
`cad/parts/generic_stack_module.py`.  All three internal pad-positioning calls
now use `c.FUTURE_CARRIAGE_PAD_X_OFFSET` directly.

**Reason:** The active stack module (`generic_stack_module.py`) was importing
the deferred carriage subsystem (`rails.py`) solely to compute the lateral pad
X-offset (`u_channel_rail_x_offset()`).  This created an unwanted coupling
between the active mk0.11.2 architecture and the deferred rail/carriage path.
The constant value (84.5 mm) is stable and derived from frozen U-channel rail
geometry constants, so a named config constant is the correct representation.

**Consequence:** No geometry change.  The side pad X-offset remains 84.5 mm.
Future carriage zone pad positions remain compatible with the frozen U-channel
rail standard.

**Files changed:** `cad/config.py`, `cad/parts/generic_stack_module.py`.

---

The following mk0.11 decisions remain valid for the **deferred** rail path:

- D-004: Generic carriage wraps open-frame standard
- D-005: U-channel rail standard frozen
- D-008: Dedicated pom_shoe / rail_profile reference files

They do not apply to the active mk0.11.2 stack prototype.

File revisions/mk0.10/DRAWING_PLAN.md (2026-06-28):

# mk0.10 Drawing Plan

## 1. Purpose

`mk0.10` is a planning and architecture-freeze revision.

The goal of this document is to define a small set of engineering drawings that must be prepared before the next major CAD implementation step.

This drawing plan exists because the project has reached a point where direct iteration through full CadQuery tower revisions is too expensive and error-prone.

The new process is:

```text
requirements -> architecture drawings -> interface drawings -> test jigs -> CadQuery implementation -> export/review
```

The drawings in this plan are not final manufacturing drawings. They are architecture and interface drawings intended to:

- reduce ambiguity before CAD implementation;
- freeze module interfaces;
- make LLM/Codex/Kimi tasks more constrained;
- separate design thinking from 3D modelling;
- prevent accidental architectural changes;
- make future revisions easier to review.

## 2. Current Project State

Latest source revision considered by this plan:

```text
mk0.9.3
```

Current relevant source assumptions:

```text
Nominal tower width: 190 mm
Nominal tower depth: 190 mm
Rear reserved zone: 30 mm
Base module height: 48 mm
RPi/SSD module height: 70 mm
Mini PC placeholder module height: 82 mm
Roof module height: 46 mm
Current stack height: 246 mm without external rod/thread allowance
```

Current rail/carriage standard:

```text
Aluminum U-channel rail: 15 x 10 x 10 x 2 mm
Estimated inner width: 11 mm
POM-C round shoe: Ø8 x 12 mm
Runner concept: short perpendicular replaceable shoes
Retention: M3 clamp screw into PETG / heat-set insert geometry
```

Current structural principles:

```text
M5 rods provide vertical compression.
PETG parts provide interfaces, frames, holders, ducts, and local support.
PETG must not be the final sliding/wear surface.
Base and roof are structural caps, not full-height device modules.
Modules must remain removable without full tower disassembly.
```

## 3. Open-Source Design References

The drawing plan should preserve lessons learned from earlier open-source research.

### 3.1 RackStack / Rackfinity lessons

Use:

- repeated modular interface;
- stackable module logic;
- metal rods / threaded rods for global compression;
- lightweight printed parts around a stronger mechanical standard.

Avoid:

- relying on massive plastic for stiffness;
- per-module one-off interfaces;
- hidden non-standard mounting logic.

### 3.2 mini-itx-nas-case lessons

Use:

- disciplined separation of printable parts and purchased parts;
- PETG/TPU material separation;
- fan/filter/service access planning;
- explicit export and print documentation.

Avoid:

- large decorative shells before airflow and serviceability are proven;
- support-heavy geometry without reason.

### 3.3 Antmicro-style documentation lessons

Use:

- clear drawings;
- BOM;
- placeholders;
- assembly notes;
- separate manufacturing/review artifacts;
- revision-specific documentation.

Avoid:

- CAD-only decisions with no written rationale;
- generated STL/STEP artifacts without explanation.

### 3.4 N5 Mini NAS / compact electronics enclosure lessons

Use:

- compact device layout;
- removable computing tray logic;
- clear cable routing;
- local airflow priority for compute module.

Avoid:

- locking the design to placeholder dimensions before real device measurement;
- finalizing Mini PC details before measuring the real Mini PC.

## 4. Drawing Strategy

The project should use three kinds of drawings.

### 4.1 Architecture drawings

Purpose:

```text
Show the whole tower layout and main engineering decisions.
```

Used for:

- architecture freeze;
- module height planning;
- airflow planning;
- rough serviceability review.

### 4.2 Interface drawings

Purpose:

```text
Define exactly how modules, rails, rods, shoes, feet, fans and filters interface.
```

Used for:

- Codex/Kimi implementation constraints;
- test jig design;
- preventing accidental interface drift.

### 4.3 Manufacturing-support drawings

Purpose:

```text
Help with printing, assembly, and fit testing.
```

Used for:

- print manifest;
- test jig instructions;
- assembly order;
- physical validation.

`mk0.10` should focus mostly on architecture and interface drawings. Full manufacturing drawings for every part are out of scope.

## 5. Drawing Output Format

Preferred output:

```text
drawings/mk0.10/*.svg
```

Recommended generation method:

```text
Python script -> SVG drawings
```

Suggested script:

```text
scripts/generate_architecture_drawings.py
```

The SVG drawings should be simple and parameter-driven. They do not need to be beautiful, but they must be readable.

The drawing generator should read dimensions from `cad/config.py` where possible.

CadQuery remains the source of truth for 3D geometry.

SVG drawings are a planning and interface layer, not a replacement for CadQuery.

Recommended future flow:

```text
cad/config.py
  -> scripts/generate_architecture_drawings.py
  -> drawings/mk0.10/*.svg

cad/config.py
  -> CadQuery parts
  -> STEP/STL exports
```

## 6. Required Drawings

`mk0.10` should produce the following drawings.

```text
01_architecture_layout_front.svg
02_architecture_layout_side.svg
03_module_interface_top.svg
04_module_interface_section.svg
05_rail_carriage_section.svg
06_carriage_top_view.svg
07_base_fan_filter_foot_section.svg
08_roof_exhaust_section.svg
09_rear_service_zone_top.svg
10_validation_test_jigs_plan.svg
```

The first five are mandatory.

The remaining five are recommended before the next full tower CAD integration.

## 7. Drawing 01 — Architecture Layout Front View

File:

```text
drawings/mk0.10/01_architecture_layout_front.svg
```

Purpose:

Show the tower from the front and fix the vertical stack architecture.

Must show:

- base module;
- RPi/SSD module;
- Mini PC placeholder module;
- roof module;
- M5 rod positions;
- front removable carriage direction;
- module boundaries;
- approximate module heights;
- total stack height;
- bottom foot clearance;
- top/bottom fan zones;
- current revision labels.

Required dimensions:

```text
TOWER_WIDTH
BASE_MODULE_HEIGHT
RPI_SSD_MODULE_HEIGHT
MINI_PC_MODULE_HEIGHT
ROOF_MODULE_HEIGHT
TOWER_HEIGHT
FOOT_HEIGHT
ROD_CENTER_OFFSET
```

Required annotations:

```text
Base and roof are structural caps, not device modules.
Carriages remove from the front.
Mini PC geometry is placeholder-based.
M5 rods provide compression, not positioning alone.
```

Design review questions:

- Are base and roof visually too tall?
- Are module heights proportional to their purpose?
- Does the tower still look like a modular blade stack?
- Is there enough front service access?

## 8. Drawing 02 — Architecture Layout Side View

File:

```text
drawings/mk0.10/02_architecture_layout_side.svg
```

Purpose:

Show airflow, rear service zone, device zones, and carriage direction in side view.

Must show:

- front side;
- rear side;
- rear reserved zone;
- bottom intake airflow;
- top exhaust airflow;
- central airflow channel;
- Mini PC airflow priority area;
- cable/service zone behind modules;
- fan positions.

Required dimensions:

```text
TOWER_DEPTH
REAR_RESERVED_DEPTH
MODULE_USABLE_DEPTH
AIRFLOW_CHANNEL_DEPTH
FAN_120_SIZE
FAN_120_THICKNESS
BOTTOM_AIR_INTAKE_CLEARANCE
```

Required annotations:

```text
All cables route through rear reserved zone.
No full-width solid floors across airflow path.
Mini PC airflow has priority.
Bottom fan intake and top fan exhaust must not be blocked.
```

Design review questions:

- Does the lower fan blow into an open path?
- Does the roof exhaust have enough open area?
- Does rear cable routing conflict with airflow?
- Are service zones separated from airflow zones?

## 9. Drawing 03 — Tower Module Interface Top View

File:

```text
drawings/mk0.10/03_module_interface_top.svg
```

Purpose:

Freeze the common top/bottom interface used by all stackable modules.

This is one of the most important drawings in the project.

Must show:

- nominal module footprint;
- M5 rod clearance holes;
- alignment pins;
- alignment sockets;
- local interface bolt positions;
- central airflow window;
- rear reserved zone;
- module frame rails;
- forbidden solid-floor zone.

Required dimensions:

```text
TOWER_WIDTH
TOWER_DEPTH
REAR_RESERVED_DEPTH
MODULE_USABLE_DEPTH
MODULE_FRAME_RAIL
ROD_CENTER_OFFSET
ROD_CLEARANCE
INTERFACE_PIN_DIAMETER
INTERFACE_PIN_CLEARANCE
INTERFACE_BOLT_CLEARANCE
INTERFACE_BOLT_CENTER_OFFSET
INTERFACE_LOCAL_BOLT_OFFSET_Y
AIRFLOW_CHANNEL_WIDTH
AIRFLOW_CHANNEL_DEPTH
```

Required annotations:

```text
M5 rods clamp the stack.
Alignment pins/sockets locate modules.
M3/M4 local screws only lock interfaces.
Airflow window must remain open unless explicitly justified.
Rear reserved zone is not a device tray area.
```

Frozen decisions:

```text
All future modules must use this interface unless mk1.x explicitly changes the standard.
```

Design review questions:

- Can every module share this interface?
- Are M5 rods far enough from airflow/device zones?
- Are pins and sockets separate from rod clearance?
- Is rear service zone preserved?

## 10. Drawing 04 — Module Interface Section

File:

```text
drawings/mk0.10/04_module_interface_section.svg
```

Purpose:

Show the vertical interface between two stacked modules.

Must show:

- lower module top ring;
- upper module bottom ring;
- alignment pin/socket engagement;
- M5 rod clearance;
- washer/nut zone concept;
- module interface height;
- local screw concept;
- airflow opening through the interface.

Required dimensions:

```text
MODULE_INTERFACE_HEIGHT
INTERFACE_PIN_HEIGHT
INTERFACE_SOCKET_DEPTH
ROD_CLEARANCE
M5_WASHER_DIAMETER
M5_WASHER_SEAT_DEPTH
M5_NUT_FLAT_DIAMETER
M5_NUT_SEAT_DEPTH
WALL_THICKNESS
MODULE_FRAME_RAIL
```

Required annotations:

```text
Plastic interface aligns modules.
M5 hardware compresses modules.
Interface must not become a massive solid slab.
Washer/nut zones should be local, not full-thickness mass.
```

Design review questions:

- Is the interface printable without excessive support?
- Is there enough engagement for alignment pins?
- Is the rod hole only clearance, not precision alignment?
- Can modules be removed without destroying the stack concept?

## 11. Drawing 05 — Rail / Carriage Cross-Section

File:

```text
drawings/mk0.10/05_rail_carriage_section.svg
```

Purpose:

Freeze and explain the rail/shoe/carriage concept before more CAD work.

Must show:

- aluminum U-channel rail;
- outer rail size 15 x 10 x 10 x 2;
- inner channel width around 11 mm;
- POM-C Ø8 shoe;
- PETG carriage side wall;
- POM-C socket;
- M3 clamp screw;
- heat-set insert / PETG boss concept;
- rail pocket carrier;
- clearance zones.

Required dimensions:

```text
RAIL_OUTER_WIDTH
RAIL_OUTER_HEIGHT
RAIL_WALL_THICKNESS
RAIL_INNER_WIDTH
RAIL_POCKET_WIDTH
RAIL_POCKET_HEIGHT
RAIL_POCKET_CLEARANCE
RUNNER_DIAMETER
RUNNER_SHOE_LENGTH
RUNNER_INSERT_DEPTH_INTO_CARRIAGE
RUNNER_PROTRUSION_FROM_CARRIAGE
RUNNER_SOCKET_DIAMETER
RUNNER_SOCKET_DEPTH
CARRIAGE_SIDE_WALL_THICKNESS
CARRIAGE_RUNNER_BOSS_DIAMETER
CARRIAGE_RUNNER_BOSS_THICKNESS
RUNNER_RETENTION_SCREW_DIAMETER
HEAT_SET_INSERT_M3_DIAMETER
HEAT_SET_INSERT_M3_DEPTH
```

Required annotations:

```text
Aluminum rail is non-printed.
POM-C shoe is non-printed wear part.
PETG must not be final sliding surface.
Clamp screw must not thread into POM-C as the primary retention.
Shoe must be replaceable.
```

Design review questions:

- Does Ø8 POM-C have enough clearance in the 15x10x10x2 rail?
- Can the shoe be installed and removed?
- Can the clamp screw be accessed?
- Is the PETG boss strong enough?
- Is the rail pocket printable?

Mandatory follow-up:

```text
Create rail_shoe_test_jig before relying on this interface in full tower print.
```

## 12. Drawing 06 — Carriage Top View

File:

```text
drawings/mk0.10/06_carriage_top_view.svg
```

Purpose:

Define the open-frame carriage layout.

Must show:

- carriage outer footprint;
- side beams;
- front pull lip;
- M3 front lock screw;
- rear cable exit;
- airflow window;
- POM-C shoe locations;
- device mounting pads;
- RPi 3B placeholder zone;
- external SSD placeholder zone;
- Mini PC placeholder zone variant.

Required dimensions:

```text
MODULE_WIDTH
MODULE_DEPTH
CARRIAGE_WALL_THICKNESS
CARRIAGE_SIDE_WALL_THICKNESS
CARRIAGE_RIB_THICKNESS
CARRIAGE_PULL_LIP_WIDTH
CARRIAGE_PULL_LIP_DEPTH
CARRIAGE_PULL_LIP_HEIGHT
CARRIAGE_LOCK_SCREW_CLEARANCE
CARRIAGE_SHOE_END_INSET
RUNNER_SHOES_PER_SIDE_RPI_SSD
RUNNER_SHOES_PER_SIDE_MINI_PC
REAR_CABLE_EXIT_WIDTH
REAR_CABLE_EXIT_HEIGHT
AIRFLOW_CHANNEL_WIDTH
AIRFLOW_CHANNEL_DEPTH
RPI3B_BOARD_WIDTH
RPI3B_BOARD_DEPTH
EXTERNAL_SSD_PLACEHOLDER_WIDTH
EXTERNAL_SSD_PLACEHOLDER_DEPTH
MINI_PC_PLACEHOLDER_WIDTH
MINI_PC_PLACEHOLDER_DEPTH
```

Required annotations:

```text
No solid carriage floor.
Local pads only where needed.
Airflow window remains open.
Runner bosses are reinforced locally.
Mini PC carriage is placeholder-based until real measurements.
```

Design review questions:

- Is the carriage too light around the shoe bosses?
- Is the front pull lip strong enough?
- Does the rear cable exit align with rear service zone?
- Is airflow preserved under devices?

## 13. Drawing 07 — Base Fan / Filter / Foot Section

File:

```text
drawings/mk0.10/07_base_fan_filter_foot_section.svg
```

Purpose:

Define the lower intake architecture and prevent a closed basement.

Must show:

- table surface;
- TPU/rubber foot;
- bottom air gap;
- foot mount socket;
- dust filter slot;
- bottom grill;
- 120 mm fan;
- base frame;
- M5 rod/corner zone;
- airflow direction upward.

Required dimensions:

```text
BASE_MODULE_HEIGHT
FOOT_HEIGHT
FOOT_DIAMETER
FOOT_SOCKET_DIAMETER
FOOT_SOCKET_DEPTH
BOTTOM_AIR_INTAKE_CLEARANCE
FAN_120_SIZE
FAN_120_THICKNESS
FAN_120_HOLE_SPACING
FAN_MOUNT_FRAME_MARGIN
FAN_GRILL_FRAME_MARGIN
FILTER_SLOT_HEIGHT
BASE_FILTER_TRAY_WIDTH
BASE_FILTER_TRAY_DEPTH
ROD_CLEARANCE
ROD_CENTER_OFFSET
```

Required annotations:

```text
Base must remain a light structural cap.
Foot clearance provides bottom intake gap.
Filter must be serviceable.
Bottom fan must not blow into a solid floor.
```

Design review questions:

- Is 12 mm bottom gap enough?
- Can the dust filter be removed?
- Does the fan have a clear intake?
- Is the base too tall for its function?

## 14. Drawing 08 — Roof Exhaust Section

File:

```text
drawings/mk0.10/08_roof_exhaust_section.svg
```

Purpose:

Define the upper exhaust architecture and keep roof mass under control.

Must show:

- roof frame;
- 120 mm exhaust fan;
- top grill;
- top guard/filter mesh slot;
- optional lightweight shroud;
- M5 rod/corner zone;
- airflow direction upward.

Required dimensions:

```text
ROOF_MODULE_HEIGHT
FAN_120_SIZE
FAN_120_THICKNESS
FAN_120_HOLE_SPACING
TOP_GUARD_FRAME_HEIGHT
FILTER_SLOT_HEIGHT
FAN_SHROUD_HEIGHT
FAN_SHROUD_WALL
FAN_MOUNT_FRAME_MARGIN
FAN_GRILL_FRAME_MARGIN
ROD_CLEARANCE
ROD_CENTER_OFFSET
```

Required annotations:

```text
Roof is a light structural cap.
Top mass should be minimized.
Exhaust must not be restricted by decorative plastic.
Shroud is allowed only if it helps airflow or mounting.
```

Design review questions:

- Is the roof still too massive?
- Does the fan exhaust have enough open area?
- Is the shroud justified?
- Are M5 nut/washer zones local rather than massive?

## 15. Drawing 09 — Rear Service Zone Top View

File:

```text
drawings/mk0.10/09_rear_service_zone_top.svg
```

Purpose:

Define how rear service routing coexists with modules and airflow.

Must show:

- rear reserved zone;
- cable path;
- power bus reserved path;
- Ethernet/USB cable path;
- fan cable path;
- rear exit from carriages;
- keep-out zones;
- relation to airflow window.

Required dimensions:

```text
REAR_RESERVED_DEPTH
REAR_CABLE_EXIT_WIDTH
REAR_CABLE_EXIT_HEIGHT
REAR_SPINE_WIDTH
REAR_SPINE_DEPTH
POWER_BUS_WIDTH
POWER_BUS_PAD_DEPTH
MODULE_USABLE_DEPTH
AIRFLOW_CHANNEL_WIDTH
AIRFLOW_CHANNEL_DEPTH
```

Required annotations:

```text
All cables route through rear service zone.
Rear service zone must not become random unused volume.
Power and signal should be separable in future revision.
Do not finalize power bus geometry in mk0.10.
```

Design review questions:

- Are cable exits aligned with the service zone?
- Does cable routing conflict with module extraction?
- Is there enough depth for connectors and bend radius?
- Is the rear service zone preserved across modules?

## 16. Drawing 10 — Validation Test Jigs Plan

File:

```text
drawings/mk0.10/10_validation_test_jigs_plan.svg
```

Purpose:

Define small validation prints before the next full tower iteration.

Must show at least four test jigs:

```text
1. rail_shoe_test_jig
2. module_interface_coupon
3. base_fan_filter_foot_coupon
4. carriage_stiffness_coupon
```

Each jig must have a specific question.

### 16.1 Rail/shoe test jig

Question:

```text
Does the aluminum U-channel 15x10x10x2 + POM-C Ø8 shoe + M3 clamp actually work?
```

Must test:

- rail pocket fit;
- shoe socket fit;
- clamp screw access;
- sliding clearance;
- shoe retention;
- print tolerances.

### 16.2 Module interface coupon

Question:

```text
Do alignment pins/sockets, M5 rod clearance and local bolts align correctly?
```

Must test:

- two stacked interface plates;
- rod holes;
- pins/sockets;
- local screws;
- tolerance and wobble.

### 16.3 Base fan/filter/foot coupon

Question:

```text
Does the lower intake package work before printing the full base?
```

Must test:

- foot socket;
- bottom gap;
- filter slot;
- grill;
- fan screw pattern.

### 16.4 Carriage stiffness coupon

Question:

```text
Are side beams, shoe bosses and pull lip stiff enough without a solid floor?
```

Must test:

- local runner boss stiffness;
- front pull lip;
- lock screw boss;
- mini PC placeholder load case.

Required annotations:

```text
No full tower print before critical interfaces are tested.
Test jigs are cheaper than full-module reprints.
Each jig must produce a pass/fail decision.
```

## 17. Drawing Style Rules

Drawings should be simple and engineering-focused.

Use:

- black/gray linework;
- clear labels;
- dimension arrows;
- section hatching only if helpful;
- color only for semantic zones if needed.

Suggested semantic colors if SVG generator supports them:

```text
PETG printed parts: light gray
TPU / rubber feet: dark gray
Metal parts: blue-gray
POM-C wear parts: yellow/orange
Airflow: blue arrows
Cable/service zones: purple
Keep-out zones: red outline
```

Do not use decorative rendering.

Do not use photorealistic views.

Each drawing should answer an engineering question.

## 18. Required Drawing Metadata

Each drawing should include:

```text
Project: Homelab Modular Tower
Revision: mk0.10 planning
Source basis: mk0.9.3
Drawing number
Drawing title
Units: mm
Status: planning / interface freeze / review
Date
```

Example:

```text
HMT-mk0.10-DWG-05
Rail / Carriage Cross-Section
Units: mm
Status: Interface Planning
```

## 19. Source-of-Truth Rules

CadQuery remains source of truth for 3D geometry.

The SVG drawings are not final manufacturing source.

However, drawings should be treated as source of truth for architecture decisions until replaced by a later architecture-freeze document.

Rules:

```text
If a drawing and CAD disagree, stop and resolve before continuing.
If a drawing lacks a dimension, do not let Codex/Kimi invent it silently.
If a subsystem is not shown in drawings, it should not be added to CAD automatically.
```

## 20. Out of Scope for mk0.10 Drawings

Do not draw or finalize:

- final Mini PC tray;
- final Mini PC duct;
- final Mini PC rear I/O;
- final UPS;
- final power distribution;
- final router module;
- final full Rear Service Spine;
- final side panels;
- decorative panels;
- production-grade toleranced drawings for every printed part.

These remain future work.

## 21. Acceptance Criteria

`DRAWING_PLAN.md` is complete when:

- required drawing list is defined;
- each drawing has a purpose;
- each drawing lists required dimensions;
- each drawing lists required annotations;
- each drawing has design review questions;
- drawings support the current mk0.9.3 architecture;
- open-source design lessons are reflected;
- test jigs are explicitly planned before full tower iteration;
- no drawing encourages adding new subsystems before interfaces are validated.

`mk0.10` drawing phase is complete when:

```text
01_architecture_layout_front.svg exists
02_architecture_layout_side.svg exists
03_module_interface_top.svg exists
04_module_interface_section.svg exists
05_rail_carriage_section.svg exists
```

Recommended completion before next full CAD integration:

```text
06_carriage_top_view.svg
07_base_fan_filter_foot_section.svg
08_roof_exhaust_section.svg
09_rear_service_zone_top.svg
10_validation_test_jigs_plan.svg
```

## 22. Recommended Next Implementation Step

After this document is created, the next task should be:

```text
Create scripts/generate_architecture_drawings.py for mk0.10.

The script should generate simple SVG drawings from cad/config.py:
- 01_architecture_layout_front.svg
- 02_architecture_layout_side.svg
- 03_module_interface_top.svg
- 04_module_interface_section.svg
- 05_rail_carriage_section.svg

Do not modify CadQuery geometry.
Do not change mk0.9.3 CAD.
Do not add new tower features.
Only generate planning drawings.
```

## 23. Engineering Principle

The project should not continue with full tower CAD changes until the main interfaces are visible and reviewable in 2D.

The purpose of `mk0.10` is to move the project from:

```text
LLM-driven CAD exploration
```

towards:

```text
engineering-driven product development
```

The drawings are not bureaucracy. They are a control layer that prevents repeated redesign, accidental interface drift, and expensive full-model rework.

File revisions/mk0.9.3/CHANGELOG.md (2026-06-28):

# mk0.9.3 Changelog

- Changed `CURRENT_REVISION` / `REVISION` to `mk0.9.3`.
- Restored and normalized rail, runner, carriage, fan, base, roof, and foot parameters in `cad/config.py`.
- Set base and roof target heights to 52 mm and reduced the roof fan shroud height.
- Kept lightweight open-frame carriage factories available for RPi + SSD and mini PC placeholder modules.
- Added explicit POM-C shoe socket and M3 clamp/heat-set-insert retention geometry to the carriage subsystem.
- Replaced fan mount, fan grill, and foot boss magic numbers with named config parameters.
- Split export categories into printed modules, printed subparts, TPU, non-printed references, placeholders, review geometry, and legacy do-not-print parts.
- Added generated `PRINT_MANIFEST.md` support for revision exports.
- Preserved M5 rod zones, fan/filter features, foot mounts, and airflow windows.

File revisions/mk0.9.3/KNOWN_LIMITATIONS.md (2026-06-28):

# mk0.9.3 Known Limitations

- No physical fit-test has been performed.
- No slicer validation has been performed.
- No strength or stiffness test has been performed.
- No heat-set insert pull-out test has been performed.
- No CFD has been performed.
- Rail/shoe system remains experimental.
- Mini PC dimensions are still unknown and placeholder-based.
- Power distribution, router module, UPS module, and full rear service spine integration are out of scope.
- CadQuery mass targets must be treated as design intent only; real PETG mass must be checked in slicer.
- Current mesh-only estimates still exceed the desired mass ranges: `base_module` is about 249.7 g PETG and `roof_module` is about 245.9 g PETG.

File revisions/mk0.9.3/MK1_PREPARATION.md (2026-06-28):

# mk0.9.3 to mk1 Preparation

Before mk1, validate the rail/shoe concept with coupon prints and real hardware:

- print a carriage side shoe socket coupon;
- test POM-C `8 x 12 mm` shoe insertion, retention, and replacement;
- test M3 clamp screw and heat-set insert pull-out resistance;
- check sliding behavior in real aluminum U-channel;
- measure the actual mini PC and replace placeholder dimensions;
- validate base and roof mass in slicer;
- verify fan/filter assembly clearance;
- review cable routing around the rear service spine before adding power/router/UPS modules.

mk0.9.3 should feed an engineering review, not a full-system print campaign.

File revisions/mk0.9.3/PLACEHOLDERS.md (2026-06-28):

# Device and Fan Placeholders

Revision: `mk0.9.3`

This manifest lists generated export artifacts. CadQuery source remains the source of truth.

No artifacts found for this category.

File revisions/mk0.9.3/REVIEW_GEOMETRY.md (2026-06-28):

# Review Geometry

Revision: `mk0.9.3`

This manifest lists generated export artifacts. CadQuery source remains the source of truth.

## airflow_clearance_zone

- Category: `review`
- STEP: `exports/mk0.9.3/review/airflow_clearance_zone.step`
- STL: `exports/mk0.9.3/review/airflow_clearance_zone.stl`

## central_airflow_channel_placeholder

- Category: `review`
- STEP: `exports/mk0.9.3/review/central_airflow_channel_placeholder.step`
- STL: `exports/mk0.9.3/review/central_airflow_channel_placeholder.stl`

## module_interface_bottom

- Category: `review`
- STEP: `exports/mk0.9.3/review/module_interface_bottom.step`
- STL: `exports/mk0.9.3/review/module_interface_bottom.stl`

## module_interface_top

- Category: `review`
- STEP: `exports/mk0.9.3/review/module_interface_top.step`
- STL: `exports/mk0.9.3/review/module_interface_top.stl`

## simplified_airflow_guide

- Category: `review`
- STEP: `exports/mk0.9.3/review/simplified_airflow_guide.step`
- STL: `exports/mk0.9.3/review/simplified_airflow_guide.stl`

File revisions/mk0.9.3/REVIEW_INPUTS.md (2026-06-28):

# mk0.9.3 Review Inputs

This review package prepares evidence for external engineering review by AI agents. It does not make unsupported engineering approval claims.

## Included Artifacts

- Export copy: `revisions/mk0.9.3/review_package/exports/`
- Analysis CSV files: `revisions/mk0.9.3/review_package/analysis/`
- Manifest documents: `revisions/mk0.9.3/review_package/manifests/`
- Revision notes copy: `revisions/mk0.9.3/review_package/revision_notes/`
- Assembly overview: `revisions/mk0.9.3/review_package/ASSEMBLY_OVERVIEW.md`
- Requirements checklist: `revisions/mk0.9.3/review_package/REVIEW_REQUIREMENTS_CHECKLIST.md`

## CSV Meaning

- `part_dimensions.csv`: bounding boxes for STL and STEP exports where the file could be parsed.
- `printability_check.csv`: axis-aligned printable STL dimensions compared with configured Bambu Lab P2S volume and long-thin geometry flags.
- `plastic_estimate.csv`: mesh solid volume and PETG/PLA mass estimates from printable STL files.
- `stl_quality.csv`: STL triangle count plus watertight/manifold indicators from edge counting.
- `duplicate_geometry_check.csv`: geometry hash and near-duplicate grouping based on STL geometry, bounding box and volume.

## What Was Measured

- Generated STL bounding boxes.
- Generated STEP bounding boxes where CadQuery could import the STEP file.
- Printable STL mesh volume.
- STL edge-based watertight/manifold indicators.
- Duplicate and near-duplicate STL signatures.

## What Was Not Measured

- Mechanical strength, stiffness, fatigue or fastener pull-out.
- Thermal performance, airflow pressure drop or CFD.
- Slicer-specific print time, supports, infill, purge, seam placement or print orientation.
- Real-world assembly tolerance stack-up.
- Electrical safety or power-distribution validation.

## Known Limitations

- Mesh volume is not slicer material usage.
- Axis-aligned print-volume checks do not search for rotated fit.
- Long-thin geometry detection is a heuristic for review prioritization.
- STL watertight/manifold checks are based on exported mesh edges and may not identify every CAD modeling issue.
- Placeholder and review geometry are included for context but are not printable production parts.

## Generated Files

- `revisions/mk0.9.3/analysis/part_dimensions.csv`
- `revisions/mk0.9.3/analysis/printability_check.csv`
- `revisions/mk0.9.3/analysis/plastic_estimate.csv`
- `revisions/mk0.9.3/analysis/stl_quality.csv`
- `revisions/mk0.9.3/analysis/duplicate_geometry_check.csv`
- `revisions/mk0.9.3/PRINTABLE_PARTS.md`
- `revisions/mk0.9.3/NON_PRINTABLE_PARTS.md`
- `revisions/mk0.9.3/PLACEHOLDERS.md`
- `revisions/mk0.9.3/REVIEW_GEOMETRY.md`
- `revisions/mk0.9.3/review_package/REVIEW_REQUIREMENTS_CHECKLIST.md`
- `revisions/mk0.9.3/review_package/ASSEMBLY_OVERVIEW.md`

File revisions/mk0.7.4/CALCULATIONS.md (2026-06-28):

# mk0.7.4 Calculations

## Baseline

The pre-mockup-reduction mk0.7.4 plastic estimate was `3764.4 g` PETG mesh-equivalent for `printable/plastic`.

## Split Joint Allowance

The split-joint interface uses a lower positive tab and an upper receiving socket.

- Tab depth: `SPLIT_JOINT_TAB_DEPTH`
- Tab height: `SPLIT_JOINT_TAB_HEIGHT`
- Socket wall: `SPLIT_JOINT_SOCKET_WALL`
- Socket clearance: `SPLIT_JOINT_SOCKET_CLEARANCE`

This is intended to remove overlapping exported volumes while preserving a mechanically visible alignment feature for coupon testing.

## Bottom Filter Retainer

The bottom filter retainer is changed from disconnected corner pads to a single connected rectangular retainer frame.

This closes the impossible detached-clip geometry, but PETG flexibility and filter-sheet retention remain coupon-required before full mockup printing.

## Rail End Mount Engagement

Rail end mount height is derived from the distance between the structural frame and the metal guide rail end plus `RAIL_END_MOUNT_RAIL_CAPTURE_DEPTH`.

The target capture depth is 10 mm for rough mockup validation. The bracket remains coupon-required because real rail tolerances and screw stack-up are not yet measured.

## Rough Mockup Mass Reduction

The mk0.7.4 rough-mockup parameter set reduces draft-print mass without changing the M5 rod, metal rail, frame screw, or module spacing standards.

Controlled reductions:

- Base sections: `MOCKUP_BASE_THICKNESS = 5.0 mm`
- Central bottom fan frame: `MOCKUP_CENTRAL_FRAME_THICKNESS = 5.0 mm`
- Base ribs: `MOCKUP_BASE_RIB_HEIGHT = 3.5 mm`
- Module tray bases: `MOCKUP_TRAY_BASE_THICKNESS = 2.4 mm`
- Module tray side walls: `MOCKUP_TRAY_SIDE_WALL = 2.4 mm`
- Module tray side height: `MOCKUP_TRAY_SIDE_HEIGHT = 10.0 mm`
- Non-structural side-panel rib height: `MOCKUP_SIDE_PANEL_RIB_HEIGHT = 1.8 mm`
- Structural side-panel rib height: `MOCKUP_SIDE_SHEAR_RIB_HEIGHT = 3.0 mm`
- Rear service spine depth: `MOCKUP_REAR_SPINE_DEPTH = 22.0 mm`
- Fan grille thickness: `MOCKUP_BOTTOM_GRILLE_THICKNESS = 3.0 mm`

After regenerating the mk0.7.4 pipeline, `printable/plastic` is estimated at `3070.1 g` PETG mesh-equivalent.

Estimated reduction:

```text
3764.4 g - 3070.1 g = 694.3 g
```

This is just below the 700 g lower target, but further reduction would start cutting into tray, frame, or side-panel interfaces that still need physical coupon validation. The current reduction is treated as the conservative rough-mockup stopping point.

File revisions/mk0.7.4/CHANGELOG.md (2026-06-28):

# mk0.7.4 Changelog

## Added

- Created mk0.7.4 revision documentation scaffold.
- Added parameterized split-joint socket dimensions.
- Added coupon test plan for high-risk fit and print interfaces.
- Added explicit `MOCKUP_*` mass-reduction parameters.
- Added rough-mockup fastener BOM and assembly sequence.
- Added print orientation and batch plan.
- Added final internal readiness review without generating an external engineering-review prompt.

## Changed

- Updated `CURRENT_REVISION` to `mk0.7.4`.
- Changed split exports to lower tab / upper socket geometry.
- Changed bottom filter retainer to a connected rectangular frame with corner reinforcement pads.
- Made left and right side-panel assembly rotations explicit.
- Moved side-panel mount rails inward to avoid structural boss overlap.
- Increased rail end mount capture depth for rough mockup validation.
- Added a vertical rail end mount screw path with matching frame holes.
- Added PETG and TPU coupon exports for split joints, rail mounts, ledges, side-panel mounts, filter retention, feet, flat PETG behavior, and fan grille sections.
- Reduced rough-mockup base, tray, side-panel rib, rear-spine, and grille mass with parameterized dimensions.

## Pending

- Physical coupon prints and external engineering review remain future work.

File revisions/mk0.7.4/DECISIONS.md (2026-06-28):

# mk0.7.4 Decisions

## Split Joint Interface

Decision: lower split sections carry the positive alignment tab, while upper split sections carry a matching socket with explicit clearance.

Reason: mk0.7.3 exported both lower and upper split parts with occupying tabs at the same joint volume. A tab/socket pair removes the confirmed overlap and keeps the split interface visible for physical coupon validation.

Tradeoff: the socket adds small local print volume and still requires a coupon to validate fit, screw access, and PETG tolerance.

## Bottom Filter Retainer

Decision: replace the detached corner-clip layout with a connected rectangular retainer frame and reinforced corner pads.

Reason: the mk0.7.3 corner clips were not physically connected to the narrow retainer body. A connected frame is less elegant than a final snap-fit but is printable, inspectable, and suitable for rough mockup validation.

Tradeoff: the connected frame uses more plastic than isolated clips, but removes a confirmed impossible geometry blocker.

## Side Panel Orientation

Decision: make left and right side-panel assembly rotations explicit.

Reason: mk0.7.3 used one global `+90 deg` rotation, which made the left panel ribs and bosses face outward. The left side now uses `-90 deg`, while the right side keeps `+90 deg`.

Tradeoff: the panels are still geometrically identical parts, so future revisions should consider mirrored part functions if the interface becomes more complex.

## Rail End Mount Screw Target

Decision: add a vertical M3 screw path through the rail end mount and matching frame holes offset from the metal rail slot.

Reason: mk0.7.3 had a visible rail end mount hole without a clear mating target. The new path gives the mockup bracket an explicit CAD target while preserving the metal rail clearance slot.

Tradeoff: screw length is still `TBD after stack check` and must be validated with a rail-end coupon.

## Rough Mockup Mass Reduction

Decision: use explicit `MOCKUP_*` parameters for draft-print mass reduction instead of local thinning inside part functions.

Reason: mk0.7.4 needs a printable rough mockup without making the long-term production intent ambiguous. Central base sections, stability wings, tray bodies, side-panel ribs, rear spine depth, and fan grilles are reduced for mockup economics while metal rods, metal guide rails, screw clearances, frame rings, and module spacing remain unchanged.

Tradeoff: the reduced parts are suitable for fit and assembly validation, not for final load or abuse testing. Mini PC and UPS trays still require conservative handling until coupon and rough mockup results exist.

## Tray Ledge Assembly Control

Decision: keep individual tray support ledges for mk0.7.4 and control misassembly risk with an indexed installation table rather than adding a new jig or redesigning the ledges into long support rails.

Reason: Chunk 5 is intended to close rough-mockup assembly ambiguity without expanding CAD scope. A dimensioned Z table is enough for a controlled mockup and preserves the existing modular ledge standard until physical feedback exists.

Tradeoff: assembly remains more error-prone than a future indexed rail or jig. If ledge placement is confusing during mockup assembly, mk0.7.5 should replace this with a printed spacing gauge or longer indexed support rail.

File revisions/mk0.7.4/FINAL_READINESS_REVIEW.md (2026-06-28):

# mk0.7.4 Final Readiness Review

## Scope

This is an internal final gate for mk0.7.4. It does not replace external engineering review and does not claim CFD, FEA, slicer simulation, or physical coupon results.

The external engineering-review prompt is intentionally not generated in this revision pass.

## Evidence Checked

| Evidence | Status | Notes |
|---|---|---|
| Revision pipeline | `CONFIRMED` | `scripts/run_revision_pipeline.py --revision mk0.7.4` completes. |
| Printable STL manifold/watertight check | `CONFIRMED` | `bad_printable_stl = 0` in current `stl_quality.csv` check. |
| Axis-aligned print-volume check | `CONFIRMED` | `bad_printability = 0` in current `printability_check.csv` check. |
| Long-thin orientation risks | `CONFIRMED` | Five printable parts remain flagged and are controlled by `PRINT_PLAN.md`. |
| Plastic estimate | `CONFIRMED` | `printable/plastic` estimate is `3070.1 g` PETG mesh-equivalent. |
| Coupon exports | `CONFIRMED` | PETG/TPU coupon STLs exist and pass mesh checks. |
| Coupon physical results | `NEEDS TEST` | Every coupon remains `NOT TESTED` until printed and inspected. |
| Fastener BOM | `CONFIRMED` | `FASTENER_BOM.md` exists; screw lengths remain stack-check gated. |
| Assembly sequence | `CONFIRMED` | `ASSEMBLY_SEQUENCE.md` exists with ledge installation table and stop conditions. |
| Print plan | `CONFIRMED` | `PRINT_PLAN.md` exists with orientation, brim, support, batch, and gating notes. |

## Finding Closure

| Finding group | Status | Evidence |
|---|---|---|
| `MA-003` split-joint overlap | `CONFIRMED CLOSED IN CAD` | Lower tab / upper socket split geometry and coupon export. |
| `MA-004` detached bottom-filter clips | `CONFIRMED CLOSED IN CAD` | Connected retainer frame and coupon export. |
| `ASM-001` side-panel orientation | `CONFIRMED CLOSED IN CAD` | Explicit left/right side-panel rotations. |
| `ASM-002` side-panel rail overlap risk | `LIKELY CONTROLLED` | Mount rails moved inward; coupon still required. |
| `MA-002` rail-end engagement | `LIKELY CONTROLLED` | 10 mm capture depth and rail-end coupon. |
| Rail-end screw target | `CONFIRMED CLOSED IN CAD` | Vertical M3 path and matching frame holes. |
| `RAP-004`, `RAP-007`, `RAP-008` | `CONFIRMED CLOSED BY DOCS` | BOM and assembly sequence identify hardware classes and counts. |
| `RAP-001` ledge misassembly risk | `LIKELY CONTROLLED` | Indexed ledge table; no physical jig yet. |
| `PRINT-*` orientation risks | `LIKELY CONTROLLED` | `PRINT_PLAN.md`; slicer and physical results still absent. |

## Stop Conditions Still Active

- Do not print full-size gated parts before the relevant coupons pass.
- Do not treat reduced mockup walls/ribs as production geometry.
- Do not install internal mains AC; mk0.7.4 remains low-voltage placeholder architecture.
- Do not claim final Mini PC, UPS, MikroTik, SSD, Raspberry Pi, fan, filter, or connector fit without real-device measurements.

## Verdict

`GO FOR PARTIAL TEST PRINT`

The recommended next physical step is the coupon batch, followed by one light tray and selected interface parts. mk0.7.4 is not cleared for an ungated full tower print because coupon results, slicer validation, and real hardware stack checks are still missing.

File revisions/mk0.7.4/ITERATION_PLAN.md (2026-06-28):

# mk0.7.4 Iteration Plan

## Purpose

mk0.7.4 is a draft print-readiness revision based on the mk0.7.3 Kimi Agents Swarm review.

The goal is not to turn the tower into a final product. The goal is to move from:

```text
mk0.7.3 verdict: GO FOR COUPON TEST PRINT ONLY
```

to:

```text
mk0.7.4 target verdict: GO FOR ROUGH MOCKUP PRINT
```

This requires resolving all confirmed geometry blockers, closing the highest-risk assembly gaps, reducing waste for the rough mockup, and producing enough documentation for a human to print and assemble the draft without reverse-engineering the Python assembly.

## Source Review

Primary review artifacts:

- `reviews/mk0.7.3/kimi_swarm_rough_print_review.md`
- `reviews/mk0.7.3/kimi_swarm_findings.csv`
- `reviews/mk0.7.3/kimi_swarm_unknowns.md`
- `reviews/mk0.7.3/kimi_swarm_action_plan.md`

## Scope

mk0.7.4 should fix or explicitly close:

- confirmed BLOCKER findings: `MA-003`, `MA-004`;
- confirmed or likely HIGH mechanical assembly findings: `ASM-001`, `ASM-002`, `MA-002`, rail-end-mount screw target;
- rough-print blockers caused by missing BOM and missing assembly order: `RAP-004`, `RAP-007`, `RAP-008`;
- first-print waste risks: `PE-001`, `PE-002`, `PE-003`, `PE-004`, `PE-005`, `PE-008`, `PE-009`;
- print-orientation risks that can be handled with documentation and coupons: `PRINT-004`, `PRINT-005`, `PRINT-007`, `PRINT-011`, `PRINT-019`;
- fit risks that must be validated before full mockup print: `RAP-002`, `RAP-003`, `RAP-005`, `RAP-009`, `RAP-011`.

## Non-Goals

These stay out of mk0.7.4 unless a change is required to preserve rough mockup assembly:

- final Mini PC duct geometry against real device ports;
- final MikroTik, Raspberry Pi, UPS, SSD, battery, and connector measurements;
- final power bus electrical design;
- fuse values, wire gauge, DC current sizing, and electrical safety review;
- CFD, thermal measurement, smoke testing, or production cooling validation;
- final side-panel shear-transfer architecture;
- final production BOM.

## Iteration Gates

Each chunk must end with one of these states:

- `PASS`: changes are implemented and verified enough to continue.
- `PASS WITH COUPON REQUIRED`: CAD is coherent, but physical validation is still needed before full print.
- `BLOCKED`: do not proceed until the issue is resolved.

Do not batch unrelated geometry fixes into the same commit. The safest rhythm is one mechanical interface per patch, then export or targeted inspection.

## Chunk 0 - Revision Setup

### Goal

Create a clean mk0.7.4 working revision without rewriting mk0.7.3 history.

### Work

- Create a branch for the revision, for example `cad/mk0.7.4`.
- Update `cad/config.py` `CURRENT_REVISION` from `mk0.7.3` to `mk0.7.4`.
- Create `revisions/mk0.7.4/` documentation files:
  - `REVISION.md`
  - `CALCULATIONS.md`
  - `DECISIONS.md`
  - `KNOWN_ISSUES.md`
  - `CHANGELOG.md`
  - `ITERATION_PLAN.md`
  - later: `ASSEMBLY_SEQUENCE.md`, `FASTENER_BOM.md`, `PRINT_PLAN.md`, `COUPON_TEST_PLAN.md`

### Exit Criteria

- `mk0.7.4` docs exist.
- No CAD geometry changes yet.
- Pipeline still refuses wrong revision and accepts the current configured revision.

## Chunk 1 - Impossible Geometry Blockers

### Findings

- `MA-003`: split-joint tabs overlap.
- `MA-004`: bottom filter retainer clips are detached.

### Work

1. In `cad/parts/service_spine.py`, redesign `_split_section()` so lower/upper split parts do not both carry occupying tabs at the same joint volume.
   - Preferred direction: lower segment has the positive alignment tab; upper segment has a matching recess or socket.
   - Apply consistently to rear spine, spine cover, power bus panel, and power bus cover split exports.
   - Keep all tab, slot, screw, and clearance dimensions parameterized in `cad/config.py`.

2. In `cad/parts/cooling.py`, redesign `bottom_filter_retainer`.
   - The clips must be physically connected to the retainer body.
   - Prefer a simple printable retainer geometry over a fragile snap-fit.
   - If clip flexibility is still unproven, document it as coupon-required, not print-ready.

### Verification

- Export affected parts.
- Confirm affected STL files remain watertight/manifold.
- Visually inspect split lower/upper parts and the retainer.
- Add mk0.7.4 `DECISIONS.md` entries for the chosen joint and filter retention approach.

### Exit Criteria

- `MA-003` is closed in CAD.
- `MA-004` is closed in CAD.
- Full mockup is still blocked until coupons pass, but impossible geometry is gone.

## Chunk 2 - Side Panel and Rail Mount Interfaces

### Findings

- `ASM-001`: left panel ribs and bosses face outward.
- `ASM-002`: right panel bosses/ribs may overlap the mount rail.
- `MA-002`: rail end mount engagement is too shallow.
- Rail end mount M3 hole has no clear mating target.
- `RAP-005`: side-panel mount rail boss strength is untested.

### Work

1. Fix left side panel orientation in `cad/assembly/tower_assembly.py`.
   - Minimal fix: left panels rotate `-90.0` while right panels keep `+90.0`.
   - Better future-proof fix: make left/right panel orientation explicit instead of relying on one global `SIDE_PANEL_ASSEMBLY_ROTATION_DEG`.

2. Check and fix right panel boss-to-rail collision.
   - If the boss/rib volume occupies the side-panel mount rail volume, add local relief/cutouts or reduce rib/boss height near rail contact.
   - Do not remove the mount standard unless a replacement standard is documented.

3. Increase rail end mount engagement.
   - Target at least 8-10 mm of rail capture for mockup.
   - Prefer parameterized mount/slot geometry in `cad/parts/rails.py`.

4. Add a real screw target for rail end mounts.
   - Either add matching frame holes or redesign the rail end mount fastening strategy.
   - The solution must be visible in CAD and reflected in the assembly sequence.

### Verification

- Render or inspect left/right side views.
- Confirm both panel exteriors are smooth and bosses face inward.
- Confirm rail end mount has useful rail capture depth.
- Confirm screw path has a mating target and is accessible.

### Exit Criteria

- Left side panel can be fastened from the intended side.
- Right side panel no longer has unresolved CAD collision against the mount rail.
- Rail end mounts are mechanically plausible before coupon testing.

## Chunk 3 - Fit Coupons Before Large Prints

### Findings

- `RAP-002`: split joints require coupon testing.
- `RAP-003`: real metal rail tolerance is unknown.
- `RAP-005`: side panel mount rail and insert boss strength are unknown.
- `RAP-009`: bottom filter retention needs physical validation.
- `RAP-011`: grille/filter orientation needs test tiles.
- Unknowns `UNK-003`, `UNK-004`, `UNK-005`, `UNK-006`, `UNK-008`.

### Work

Create a coupon test plan and, where practical, small exported coupon geometry:

- split-joint tab/socket with M3 screw path;
- rail end mount plus real metal guide rail interface;
- tray support ledge plus rail plus representative tray edge;
- side panel mount rail plus representative panel section with insert boss;
- bottom filter retainer plus filter frame plus real filter sheet;
- TPU foot plus PETG socket;
- large flat PETG tile, 50 x 50 x 3 mm;
- representative top fan grille section.

### Verification

Each coupon gets a simple result table:

```text
Coupon | Result | Required Change | Status
```

### Exit Criteria

- No full-size spine, tray stack, side panel set, or grilles are printed before the relevant coupons pass.
- Coupon failures become new mk0.7.4 findings and feed back into Chunk 1 or Chunk 2.

## Chunk 4 - Mockup Mass Reduction

### Findings

- `PE-008`: total printable plastic is excessive.
- `PE-001`: central bottom fan frame is overbuilt.
- `PE-002`: base assembly is overbuilt for rough mockup.
- `PE-003`: trays are heavy for static fit-check.
- `PE-004`: side panel ribs are heavy for a mockup.
- `PE-005`: rear service spine depth may be excessive for rough routing.
- `PE-009`: bottom fan grille thickness is inconsistent with `FAN_GRILLE_THICKNESS`.

### Work

Add a controlled mockup parameter set instead of random local thinning:

- `MOCKUP_BASE_THICKNESS`
- `MOCKUP_CENTRAL_FRAME_THICKNESS`
- `MOCKUP_TRAY_BASE_THICKNESS`
- `MOCKUP_TRAY_SIDE_WALL`
- `MOCKUP_SIDE_SHEAR_RIB_HEIGHT`
- `MOCKUP_REAR_SPINE_DEPTH`
- `MOCKUP_BOTTOM_GRILLE_THICKNESS` or direct use of existing `FAN_GRILLE_THICKNESS`

Preferred policy:

- keep `mini_pc_tray` and `ups_power_tray` more conservative than light trays;
- reduce only mockup geometry, not the future production intent;
- document every reduction in `CALCULATIONS.md` with the tradeoff.

### Verification

- Regenerate plastic estimate.
- Compare mk0.7.4 mass against mk0.7.3.
- Target reduction: 700-1000 g mesh-equivalent if achievable without weakening the rough assembly path.

### Exit Criteria

- Plastic mass is reduced enough to make the draft print economically sane.
- No reduced part becomes thinner than the intended printable wall/rib standard.

## Chunk 5 - Assembly Practicality and BOM

### Findings

- `RAP-001`: 24 tray support ledges create high assembly risk.
- `RAP-004`: no assembly instructions or BOM.
- `RAP-006`: base fastener access is under-modeled.
- `RAP-007`: M5 nuts/washers missing from manifest.
- `RAP-008`: M3 screws/inserts missing from manifest.
- `RAP-012`: too many unique print and assembly steps for an unmanaged mockup.

### Work

1. Produce `revisions/mk0.7.4/FASTENER_BOM.md`.
   - M5 rods, nuts, washers, optional nylock/acorn nuts.
   - M3 screws by length class if known; otherwise mark length as `TBD after stack check`.
   - M3 heat-set inserts.
   - Any required real metal guide rails.

2. Produce `revisions/mk0.7.4/ASSEMBLY_SEQUENCE.md`.
   - Base sections.
   - M5 rods and corner blocks.
   - Metal guide rails.
   - Rail end mounts.
   - Tray support ledges.
   - Tray stack.
   - Rear service spine and power bus placeholders.
   - Side panel mount rails and panels.
   - Fans, filter frame, retainer, feet.

3. Decide how to reduce ledge misassembly risk.
   - Option A: add a printed spacing jig/index gauge.
   - Option B: replace individual ledges with longer indexed support rails.
   - Option C: keep individual ledges but add a dimensioned installation table and assembly marks.

4. Model or document base fastener access.
   - Bolts inserted from top/bottom must be clear before the tower is built up.

### Verification

- A human can identify all hardware before printing.
- Assembly order does not require removing already-installed major modules.
- Ledge installation has either a jig or a clear indexed measurement procedure.

### Exit Criteria

- `RAP-004`, `RAP-007`, `RAP-008` are closed by documentation.
- `RAP-001` is either reduced by CAD or controlled by jig/instructions.

## Chunk 6 - Print Plan and Orientation Controls

### Findings

- `PRINT-004`: top fan grille warp risk.
- `PRINT-005`: bottom filter frame warp risk.
- `PRINT-007`: rear service spine tall narrow print risk.
- `PRINT-011`: trays warp at thin base.
- `PRINT-017`: bottom fan cartridge brim recommended.
- `PRINT-019`: rear spine covers should not be printed upright.
- `PRINT-018`: power bus covers/panels need careful orientation.

### Work

Produce `revisions/mk0.7.4/PRINT_PLAN.md` with per-part orientation:

- print flat, edge, or wide-face orientation;
- brim width;
- supports yes/no;
- material: PETG/TPU;
- first-layer caution for large flat parts;
- batch grouping recommendation;
- do-not-print-yet markers for parts gated by coupons.

### Verification

- Every printable part has a recommended orientation.
- Large flat parts have brim/enclosure guidance.
- Tall narrow parts are either reoriented or explicitly marked as risky.

### Exit Criteria

- No part relies on guesswork at slicing time.

## Chunk 7 - Full mk0.7.4 Pipeline and Review Package

### Work

Run the revision pipeline for mk0.7.4:

```text
conda run -n cadquery python scripts/run_revision_pipeline.py --revision mk0.7.4
```

Verify outputs:

- exports refresh successfully;
- all printable STLs are watertight/manifold;
- all parts fit the target build volume;
- plastic estimate reflects mockup reduction;
- review package includes updated docs and manifests.

### Exit Criteria

- No pipeline failure.
- No new blocker from export, manifold, or build-volume checks.

## Chunk 8 - Final Readiness Review

### Work

Re-run external engineering review on the mk0.7.4 package.

The review prompt should require:

- evidence status: `CONFIRMED`, `LIKELY`, `UNCERTAIN`, `NEEDS TEST`;
- no invented CFD, FEA, slicer, or physical test results;
- final verdict: `GO FOR FULL PRINT`, `GO FOR PARTIAL TEST PRINT`, or `NO-GO UNTIL BLOCKERS ARE FIXED`.

### Exit Criteria

mk0.7.4 can be called draft print-ready only if:

- all blocker geometry is fixed;
- side panel and rail interfaces are mechanically plausible;
- coupon-required interfaces either passed or are excluded from full print;
- BOM and assembly sequence exist;
- print orientation plan exists;
- pipeline passes;
- external review gives at least `GO FOR PARTIAL TEST PRINT`, ideally `GO FOR ROUGH MOCKUP PRINT`.

## Recommended Commit Slices

1. `mk0.7.4 docs scaffold and iteration plan`
2. `fix split joints and filter retainer blockers`
3. `fix side panel orientation and rail mount interfaces`
4. `add coupon test plan and coupon exports`
5. `add mockup mass reduction parameters`
6. `add fastener BOM and assembly sequence`
7. `add print plan and orientation guidance`
8. `refresh mk0.7.4 exports and review package`

## Finding-to-Chunk Map

| Finding | Chunk |
|---|---|
| `MA-003` | Chunk 1 |
| `MA-004` | Chunk 1 |
| `ASM-001` | Chunk 2 |
| `ASM-002` | Chunk 2 |
| `MA-002` | Chunk 2 |
| Rail end mount screw target | Chunk 2 |
| `RAP-002` | Chunk 3 |
| `RAP-003` | Chunk 3 |
| `RAP-005` | Chunk 3 |
| `RAP-009` | Chunk 3 |
| `RAP-011` | Chunk 3 |
| `PE-001` | Chunk 4 |
| `PE-002` | Chunk 4 |
| `PE-003` | Chunk 4 |
| `PE-004` | Chunk 4 |
| `PE-005` | Chunk 4 |
| `PE-008` | Chunk 4 |
| `PE-009` | Chunk 4 |
| `RAP-001` | Chunk 5 |
| `RAP-004` | Chunk 5 |
| `RAP-006` | Chunk 5 |
| `RAP-007` | Chunk 5 |
| `RAP-008` | Chunk 5 |
| `RAP-012` | Chunk 5 |
| `PRINT-004` | Chunk 6 |
| `PRINT-005` | Chunk 6 |
| `PRINT-007` | Chunk 6 |
| `PRINT-011` | Chunk 6 |
| `PRINT-017` | Chunk 6 |
| `PRINT-018` | Chunk 6 |
| `PRINT-019` | Chunk 6 |
| `ASM-005` | Chunk 7 / Chunk 8 |

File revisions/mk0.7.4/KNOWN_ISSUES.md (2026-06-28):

# mk0.7.4 Known Issues

## Coupon-Required Interfaces

- Split-joint tab/socket fit is CAD-coherent but not physically validated.
- Bottom filter retainer stiffness and filter-sheet grip are not physically validated.
- Rail end mount engagement and screw target are CAD-coherent but not physically validated.
- Side panel orientation and rail clearance are CAD-coherent but not physically validated.
- Coupon STLs exist, but every coupon result remains `NOT TESTED` until a physical print is inspected.
- Mockup mass reduction is CAD/export validated only; reduced walls and ribs still need coupon and rough-assembly feedback before being treated as production geometry.
- M3 screw lengths remain `TBD after stack check`; mk0.7.4 identifies hardware classes and counts but does not claim final screw lengths.
- Tray ledge misassembly is controlled by a table, not by a physical jig; a jig or indexed rail may still be needed after mockup feedback.
- Print orientations are planning recommendations only; no slicer simulation or physical print result is claimed.
- Final readiness verdict is limited to partial test print; full tower print remains gated by physical coupon results.

## Deferred Non-Goals

- Final electrical sizing and connector selection remain out of scope.
- Final Mini PC duct geometry remains out of scope until real device measurements are available.
- No CFD, FEA, slicer, or physical-test result is claimed for mk0.7.4 until generated externally.

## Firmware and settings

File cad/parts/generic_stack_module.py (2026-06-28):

"""mk0.11.2 generic stack module — stack-through-rod layer.

Active architecture for mk0.11.2: a stackable module layer compressed between
base_pedestal and top_cap by four M5 through-rods.

Each module reserves future carriage/side-adapter mounting zones without
implementing rails, POM-C shoe sockets, or sliding carriage geometry.

Design intent:
- Stackable module layer with top/bottom interface rings.
- 4x M5 pass-through holes aligned by config offsets.
- Local reinforced compression pad zones around M5 corner posts.
- Central vertical airflow opening (no solid floor).
- Rear service reserved cutout/zone.
- Internal device mounting placeholder grid.
- Front handle/label zone placeholder.
- Future carriage/side adapter mounting zones (pads + M3 bosses only).
- PETG printable as a standalone part.
"""

import cadquery as cq

from .. import config as cfg
from . import module_interface


def _corner_rod_points(c=cfg) -> list[tuple[float, float]]:
    x = c.TOWER_WIDTH / 2 - c.ROD_CENTER_OFFSET
    y = c.TOWER_DEPTH / 2 - c.ROD_CENTER_OFFSET
    return [(-x, -y), (x, -y), (x, y), (-x, y)]


def _make_frame_ring(c=cfg) -> cq.Workplane:
    """Single horizontal frame ring with airflow and rear service clearance."""
    ring = cq.Workplane("XY").box(c.TOWER_WIDTH, c.TOWER_DEPTH, c.MODULE_INTERFACE_HEIGHT)
    inner = (
        cq.Workplane("XY")
        .box(
            c.TOWER_WIDTH - 2 * c.MODULE_FRAME_RAIL,
            c.MODULE_USABLE_DEPTH - 2 * c.MODULE_FRAME_RAIL,
            c.MODULE_INTERFACE_HEIGHT + c.FILLET_RADIUS,
        )
        .translate((0, -c.REAR_RESERVED_DEPTH / 2, 0))
    )
    rear = (
        cq.Workplane("XY")
        .box(
            c.TOWER_WIDTH - 2 * c.MODULE_FRAME_RAIL,
            c.REAR_RESERVED_DEPTH - c.MODULE_FRAME_RAIL,
            c.MODULE_INTERFACE_HEIGHT + c.FILLET_RADIUS,
        )
        .translate((0, c.TOWER_DEPTH / 2 - c.REAR_RESERVED_DEPTH / 2, 0))
    )
    return ring.cut(inner).cut(rear)


def _make_vertical_airflow_opening(height: float, c=cfg) -> cq.Workplane:
    """Central vertical airflow channel through the module interior."""
    return (
        cq.Workplane("XY")
        .box(
            c.AIRFLOW_CHANNEL_WIDTH,
            c.AIRFLOW_CHANNEL_DEPTH,
            height + c.FILLET_RADIUS,
        )
        .translate((0, -c.REAR_RESERVED_DEPTH / 2, 0))
    )


def _apply_compression_pads(part: cq.Workplane, c=cfg) -> cq.Workplane:
    """Washer seat pockets on top and bottom faces at each M5 corner post."""
    pad_radius = c.STACK_MODULE_COMPRESSION_PAD_DIAMETER / 2
    pad_depth = c.STACK_MODULE_COMPRESSION_PAD_DEPTH
    for x, y in _corner_rod_points(c):
        part = part.faces(">Z").workplane(centerOption="CenterOfBoundBox").center(x, y).circle(pad_radius).cutBlind(
            -pad_depth
        )
        part = part.faces("<Z").workplane(centerOption="CenterOfBoundBox").center(x, y).circle(pad_radius).cutBlind(
            -pad_depth
        )
    return part


def _make_future_carriage_mount_zones(height: float, c=cfg) -> cq.Workplane:
    """Left/right reinforced flat pads reserved for future side adapters.

    Pads span the full module height so they are physically anchored to both
    the top and bottom frame rings.  They are centered on the U-channel rail
    lateral position and do not include rail pockets, shoe sockets, or any
    sliding features.
    """
    pads = None
    x_rail = c.FUTURE_CARRIAGE_PAD_X_OFFSET
    y_center = -c.REAR_RESERVED_DEPTH / 2

    for sign in (-1, 1):
        pad = (
            cq.Workplane("XY")
            .box(
                c.FUTURE_CARRIAGE_PAD_WALL,
                c.FUTURE_CARRIAGE_PAD_WIDTH,
                height,
            )
            .translate((sign * x_rail, y_center, 0.0))
        )
        pads = pad if pads is None else pads.union(pad)

    return pads.tag("future_carriage_mount_zones")


def _make_future_side_adapter_mount_points(height: float, c=cfg) -> cq.Workplane:
    """M3 insert bosses on future side pads — DEFERRED, not called in mk0.11.2 shell.

    This function is kept for reference but is NOT included in the printable
    part because the boss geometry is disconnected from the side pad body
    and produces floating islands.  Reactivate only after the side pad
    geometry is redesigned for full connectivity.
    """
    bosses = None
    x_rail = c.FUTURE_CARRIAGE_PAD_X_OFFSET
    y_center = -c.REAR_RESERVED_DEPTH / 2
    z_center = c.FUTURE_CARRIAGE_PAD_VERTICAL_CENTER_Z
    half_spacing = c.FUTURE_SIDE_ADAPTER_MOUNT_SPACING_Y / 2
    y_offsets = (
        [0.0]
        if c.FUTURE_SIDE_ADAPTER_MOUNT_COUNT <= 1
        else [-half_spacing, half_spacing][: c.FUTURE_SIDE_ADAPTER_MOUNT_COUNT]
    )

    for sign in (-1, 1):
        x_face = sign * (x_rail + sign * c.FUTURE_CARRIAGE_PAD_WALL / 2)
        for y_off in y_offsets:
            boss = (
                cq.Workplane("YZ")
                .circle(c.INSERT_BOSS_DIAMETER / 2)
                .extrude(c.INSERT_BOSS_HEIGHT)
                .translate((x_face, y_center + y_off, z_center))
            )
            bore = (
                cq.Workplane("YZ")
                .circle(c.M3_CLEARANCE / 2)
                .extrude(c.INSERT_BOSS_HEIGHT + c.FILLET_RADIUS)
                .translate((x_face, y_center + y_off, z_center))
            )
            boss = boss.cut(bore)
            bosses = boss if bosses is None else bosses.union(boss)

    return bosses.tag("future_side_adapter_mount_points")


def _make_future_bottom_adapter_pads(c=cfg) -> cq.Workplane:
    """Optional bottom adapter pad placeholders on the lower interface ring."""
    pads = None
    x_rail = c.FUTURE_CARRIAGE_PAD_X_OFFSET
    z = -c.GENERIC_STACK_MODULE_HEIGHT / 2 + c.MODULE_INTERFACE_HEIGHT / 2
    y_center = -c.REAR_RESERVED_DEPTH / 2

    for sign in (-1, 1):
        pad = (
            cq.Workplane("XY")
            .box(
                c.FUTURE_BOTTOM_ADAPTER_PAD_WIDTH,
                c.FUTURE_BOTTOM_ADAPTER_PAD_DEPTH,
                c.FUTURE_BOTTOM_ADAPTER_PAD_HEIGHT,
            )
            .translate((sign * x_rail, y_center, z))
        )
        pads = pad if pads is None else pads.union(pad)

    return pads.tag("future_bottom_adapter_pads")
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

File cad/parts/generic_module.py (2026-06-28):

"""mk0.11 generic removable module shell — DEFERRED carriage/rail era.

Superseded for active work by `generic_stack_module.py` in mk0.11.2
(stack-through-rod architecture).  This file is preserved unchanged for
the deferred sliding carriage / rail upgrade path.

See `cad/deferred/README.md` for deferred vs active architecture status.

First subsystem target for the mk0.11 subsystem-first workflow.

This is a device-agnostic module body that establishes the structural shell,
airflow path, rear service zone clearance, rail pocket integration points,
and front handle zone — without committing to any device layout.

Design intent:
- Dimensionally compatible with the tower module standard.
  Uses TOWER_WIDTH × TOWER_DEPTH outer footprint with MODULE_FRAME_RAIL border.
- Compatible with the mk0.9.3 open-frame carriage and POM-C shoe rail standard.
  Rail pocket carriers produced by make_module_rail_pocket_features().
- Reserves REAR_RESERVED_DEPTH zone for Rear Service Spine cabling.
- Open central volume for vertical airflow (no solid floor between rings).
- M5 rod clearance at all four corner posts via apply_module_interface_features().
- Front handle placeholder at lower front face for ergonomic extraction.
- PETG printable in two orientations (upright, with support on frame rings).

Not included here:
- Device-specific mounting pads, standoffs, retainers.
- UPS, router, or power bus geometry.
- Decorative surfaces.
- Carriage geometry (see cad/parts/module_carriage.py).
"""

import cadquery as cq

from .. import config as cfg
from . import module_interface, rails


def _make_frame_ring(c=cfg) -> cq.Workplane:
    """Single horizontal frame ring (MODULE_INTERFACE_HEIGHT thick).

    The ring spans the full tower footprint and leaves an open interior
    zone for airflow and the module interior. The rear reserved zone is
    also cleared to maintain Rear Service Spine access.
    """
    ring = cq.Workplane("XY").box(c.TOWER_WIDTH, c.TOWER_DEPTH, c.MODULE_INTERFACE_HEIGHT)

    # Central interior cutout — leaves MODULE_FRAME_RAIL-wide perimeter on
    # three sides (front, left, right) and full depth on the rear zone.
    inner = (
        cq.Workplane("XY")
        .box(
            c.TOWER_WIDTH - 2 * c.MODULE_FRAME_RAIL,
            c.MODULE_USABLE_DEPTH - 2 * c.MODULE_FRAME_RAIL,
            c.MODULE_INTERFACE_HEIGHT + c.FILLET_RADIUS,
        )
        .translate((0, -c.REAR_RESERVED_DEPTH / 2, 0))
    )

    # Rear zone clearance — maintains cable routing space through Rear Service Spine.
    rear = (
        cq.Workplane("XY")
        .box(
            c.TOWER_WIDTH - 2 * c.MODULE_FRAME_RAIL,
            c.REAR_RESERVED_DEPTH - c.MODULE_FRAME_RAIL,
            c.MODULE_INTERFACE_HEIGHT + c.FILLET_RADIUS,
        )
        .translate((0, c.TOWER_DEPTH / 2 - c.REAR_RESERVED_DEPTH / 2, 0))
    )

    return ring.cut(inner).cut(rear)


def make_generic_module_shell(c=cfg) -> cq.Workplane:
    """Structural shell for the generic module.

    Consists of:
    - Bottom and top frame rings (MODULE_INTERFACE_HEIGHT each).
    - Four corner posts (CORNER_POST_SIZE × CORNER_POST_SIZE × height)
      at M5 rod positions. Rod clearance holes are added by
      apply_module_interface_features() in make_generic_module().
    - Rail pocket carrier features on both lateral sides, produced by
      rails.make_module_rail_pocket_features().

    The space between the two rings is intentionally open — no floor,
    no infill. The carriage (module_carriage.py) occupies this space
    as a separate printable part.
    """
    height = c.GENERIC_MODULE_HEIGHT

    bottom_ring = _make_frame_ring(c).translate(
        (0, 0, -height / 2 + c.MODULE_INTERFACE_HEIGHT / 2)
    )
    top_ring = _make_frame_ring(c).translate(
        (0, 0, height / 2 - c.MODULE_INTERFACE_HEIGHT / 2)
    )
    shell = bottom_ring.union(top_ring)

    # Corner posts — solid pillars connecting both rings at the M5 rod corners.
    # Dimensions use CORNER_POST_SIZE to match the corner block geometry used
    # elsewhere in the tower. Rod clearance holes are cut later by
    # apply_module_interface_features() to avoid double-cutting.
    post_size = c.CORNER_POST_SIZE
    x = c.TOWER_WIDTH / 2 - c.ROD_CENTER_OFFSET
    y = c.TOWER_DEPTH / 2 - c.ROD_CENTER_OFFSET
    for px, py in [(-x, -y), (x, -y), (x, y), (-x, y)]:
        post = cq.Workplane("XY").box(post_size, post_size, height).translate((px, py, 0))
        shell = shell.union(post)

    # Rail pocket carrier features — printed side flanges that capture the
    # U-channel rail and locate its end stops.  Reuses mk0.9.3 standard
    # geometry without any modification.
    rail_pockets = rails.make_module_rail_pocket_features(height, c.GENERIC_MODULE_RAIL_LENGTH)
    shell = shell.union(rail_pockets)

    return shell.tag("generic_module_shell")


def make_generic_module_front_handle(c=cfg) -> cq.Workplane:
    """Front handle placeholder on the module front face.

    A forward-protruding pull lip centered on X at the lower front of
    the module, flush with the tower front face. Dimensioned to match the
    existing carriage pull lip standard (CARRIAGE_PULL_LIP_*) so that
    the handle zone is consistent across all module types.

    Intentionally minimal — no lock screw boss, no label recess, no
    ergonomic shaping. These features are added in device-specific modules
    after the generic prototype is validated.
    """
    height = c.GENERIC_MODULE_HEIGHT

    # Z position: lower 1/3 of the module front face, matching the approximate
    # height of the carriage pull lip when the carriage sits at deck level.
    handle_z = -height / 2 + c.GENERIC_MODULE_HANDLE_HEIGHT / 2

    lip = (
        cq.Workplane("XY")
        .box(
            c.CARRIAGE_PULL_LIP_WIDTH,
            c.CARRIAGE_PULL_LIP_DEPTH,
            c.GENERIC_MODULE_HANDLE_HEIGHT,
        )
        .translate(
            (
                0,
                -(c.TOWER_DEPTH / 2) - c.CARRIAGE_PULL_LIP_FRONT_OFFSET,
                handle_z,
            )
        )
    )
    return lip.tag("generic_module_front_handle")
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

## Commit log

2026-06-27 Freeze CAD revision mk0.1
    [bottom_fan_panel.step, bottom_fan_panel.stl, corner_block.step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]
2026-06-27 Ignore generated CAD artifacts
    [bottom_fan_panel.step, bottom_fan_panel.stl, corner_block.step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]
2026-06-27 Develop mk0.2 carriage and CAD architecture
2026-06-27 Add CAD drawing sheet renderer
2026-06-27 Implement CAD revision mk0.4
2026-06-27 Add mk0.5 stability and torsion revision
    [side_panels.py]
2026-06-27 Prepare mk0.7 CAD revision
2026-06-27 Add mk0.7 engineering review package
    [airflow_path_review.step, airflow_path_review.stl, blocked_air_zones_review.step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]
2026-06-27 Ignore generated CAD and render artifacts
    [airflow_path_review.step, airflow_path_review.stl, blocked_air_zones_review.step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]
2026-06-27 Generate mk0.7.1 analysis package pipeline
    [duplicate_geometry_check.csv, part_dimensions.csv, plastic_estimate.csv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]
2026-06-27 Add mk0.7.3 rough assembly revision
    [duplicate_geometry_check.csv, kimi_swarm_findings.csv, part_dimensions.csv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]
2026-06-27 Start mk0.7.4 print readiness revision
    [duplicate_geometry_check.csv, part_dimensions.csv, plastic_estimate.csv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]
2026-06-27 Add mk0.7.4 fit test coupons
    [duplicate_geometry_check.csv, part_dimensions.csv, printability_check.csv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]
2026-06-27 Add mk0.7.4 mockup mass reduction parameters
    [duplicate_geometry_check.csv, part_dimensions.csv, plastic_estimate.csv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]
2026-06-27 Add mk0.7.4 rough mockup BOM and assembly sequence
2026-06-27 Add mk0.7.4 print orientation plan
2026-06-28 Add mk0.9 modular CAD prototype
    [duplicate_geometry_check.csv, part_dimensions.csv, plastic_estimate.csv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]
2026-06-28 mk0.9.1: lightweight corrective revision
    - Lightweight base_module (frame only, restored foot mounts, bottom grill, filter slot)
    - Lightweight roof_module (kept as-is, already frame-based)
    - New rail/carriage subsystem: aluminum U-channel 15x10x10x2 mm, POM-C Ø8 shoes
    - Open-frame carriages for RPi/SSD (4 shoes) and Mini PC placeholder (6 shoes)
    - M3 clamp screw retention into PETG boss, no threading into POM-C
    - Restored TPU foot placeholders in assembly
    - Updated config.py with mk0.9.1 rail/carriage parameters and weight targets
    - Updated part_registry.py and export categories for new parts
    - Added revisions/mk0.9.1 documentation (README, CHANGELOG, DESIGN_NOTES, BOM, PRINTING, ASSEMBLY,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
2026-06-28 Implement mk0.9.2 rail carriage revision
    [duplicate_geometry_check.csv, part_dimensions.csv, plastic_estimate.csv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]
2026-06-28 Prepare mk0.9.3 corrective CAD revision
    [duplicate_geometry_check.csv, part_dimensions.csv, plastic_estimate.csv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]
2026-06-28 Implement mk0.11 subsystem-first workflow: generic module + carriage + rail interface
    Closes the mk0.10 drawing-first iteration (SVG drawings archived as-is).
    Introduces subsystem-first / testable CAD-first process starting with a
    device-agnostic generic module that validates the module/carriage/rail
    interface before full tower integration.
    New CAD parts:
    - cad/parts/generic_module.py: generic removable module shell (70 mm, PETG)
    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
2026-06-28 Separate legacy full-tower CAD from active mk0.11 workflow.
    Move historical parts, tower assembly, and mk0.10 drawing artifacts into cad/legacy/, keep backward-compat stubs at original paths, and document the subsystem-first structure for mk0.11.1.
2026-06-28 Implement mk0.11.2 stack-through-rod prototype and fix stack module printability
    Add base_pedestal, generic_stack_module, and top_cap with stack_test_assembly validation path. Defer carriage/rail sliding architecture to mk011_deferred exports. Fix floating M3 bosses, mount grid pads, carriage pad placement, corner rod alignment, and alignment pins for single-body printable exports.
    [generic_module.py, generic_stack_module.py, module_carriage.py]
2026-06-28 mk0.11.2 compliance audit: decouple rails import, add requirement checklist
    Add FUTURE_CARRIAGE_PAD_X_OFFSET to config.py (mk0.11.2 section).
    Value 84.5 mm derived from frozen U-channel rail constants.
    Remove rails module import from generic_stack_module.py.
    Replace all three rails.u_channel_rail_x_offset() calls with
    c.FUTURE_CARRIAGE_PAD_X_OFFSET. No geometry change.
    Add D-013 to revisions/mk0.11.2/DECISIONS.md documenting the
    config constant and architecture isolation rationale.
    Add requirement verification checklist table and future readiness
    assessment to revisions/mk0.11.2/VALIDATION_PLAN.md.
    Create reviews/mk0.11.2/engineering_review.md with full audit
    findings: compliance matrix, cri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
    [generic_stack_module.py]
2026-06-29 Prepare mk0.12 CAD skeleton revision
